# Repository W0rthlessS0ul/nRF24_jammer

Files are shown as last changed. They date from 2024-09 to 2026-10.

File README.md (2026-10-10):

<div align="center">
  
  <h1> 🌟 nRF24 Jammer 🌟 </h1>
</div>

Welcome to the **nRF24 Jammer** repository! 🎉 Dive into the world of RF interference with this unique project based on the ESP32 and nRF24 technology.

## 📚 Table of Contents
- [🚀 What Can You Do with This?](#-what-can-you-do-with-this)
- [📱 Ported Firmware](#-ported-firmware)
- [📟 Supported & Community PCBs](#-supported-&-community-pcbs)
- [📋 List of Components](#-list-of-components)
- [🧑‍🔧 Let's Get Started with Soldering!](#-lets-get-started-with-soldering)
- [🛠️ Build From Source](#-build-from-source)
- [📦 Flash Firmware](#-flash-firmware)
- [🎮 Device Control](#-device-control)
- [🌐 Web Interface](#-Web-Interface)
- [🔌 Serial Interface](#-Serial-Interface)
- [🎉 Final Outcome](#-final-outcome)
- [🙏 Acknowledgments](#-acknowledgments)
- [🤝 Project Supporters](#-project-supporters)
- [❤️ Support the project](#-support-the-project)
- [⭐ Star History](#-star-history)

-----

## 🚀 What Can You Do with This?
This amazing jammer is built on the **ESP32** architecture integrated with **configurable numbers of nRF24** modules. With its extraordinary capabilities, you can effectively disrupt signals across different technologies including:
- **Bluetooth** 🔊
- **BLE** 📱
- **Drones** 🚁
- **Wi-Fi** 📶
- **Zigbee**📡

-----

## 📱 Ported Firmware

| Device | Repository URL |
|---|---|
| Flipper Zero | [FZ_nRF24_jammer](https://github.com/W0rthlessS0ul/FZ_nRF24_jammer) |
| LOLIN32 Lite | [nRF24_jammer](https://github.com/gitati16/nRF24_jammer) |

-----

## 📋 List of Components
To bring this project to life, you will need the following components:

1. <details><summary><b>nRF24 modules 🛠️</b></summary>

    *Any nRF24 modules are suitable, but **CDEBYTE E01-2G4M27D** is recommended*

   </details>

2. **ESP-WROOM-32** ⚙️
3. **16V capacitors** rated at **100µF** 🔋
4. **128x32 or 128x64 OLED display** 📺 *(optional)*
5. **Tactile button** 🔘 *(optional)*

-----

## 📟 Supported & Community PCBs

| Preview | Author | Rev | Board README |
|---|---|-----|---|
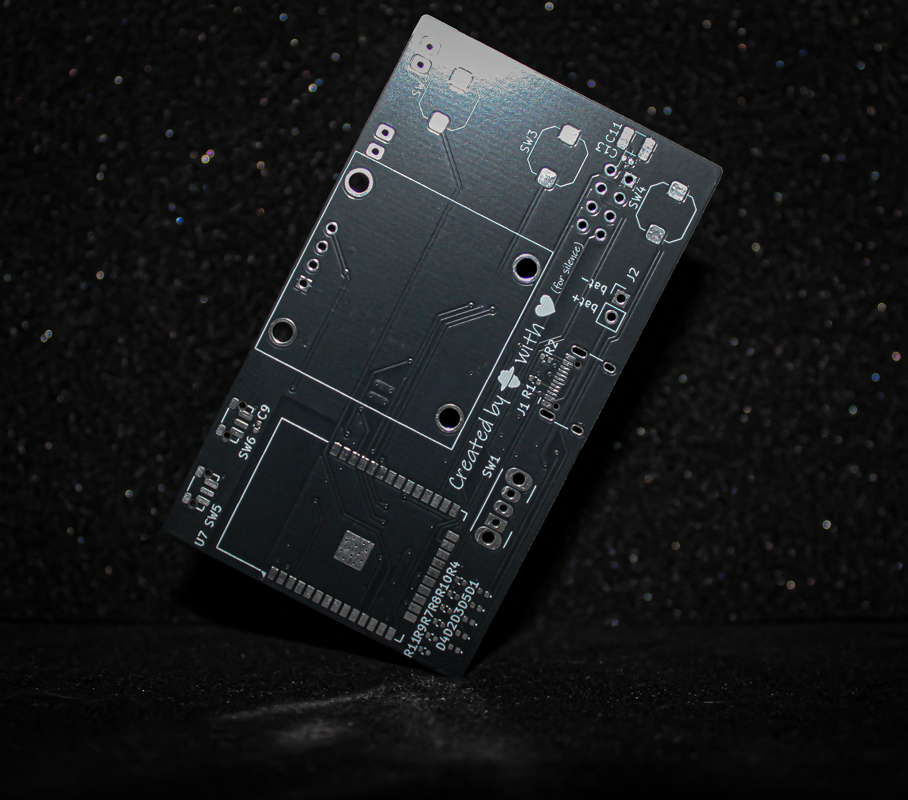
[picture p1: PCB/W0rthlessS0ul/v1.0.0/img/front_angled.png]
|  | [@W0rthlessS0ul](https://github.com/W0rthlessS0ul) | `v1.0.0` | [README](/PCB/W0rthlessS0ul/v1.0.0/README.md) |

> 💡 **Want to contribute your own PCB design?**  
> If you feel confident in designing a high-quality PCB, feel free to submit your board via a **Pull Request**!  
> 
> - **Well-engineered and verified designs** will be merged directly into the repository.  
> - If there are any doubts regarding layout quality, routing, or component selection, a thread will be opened in **[Discussions](https://github.com/W0rthlessS0ul/nRF24_jammer/discussions)** so the community can review, discuss, and vote on whether it should be added.

-----

## 🧑‍🔧 Let's Get Started with Soldering!

### Connecting First nRF24 module (**optional**)
| **Pin Name** | **ESP32 GPIO** | **Connection** |
|---|---|---|
| VCC | 3.3V | (+) capacitor |
| GND | GND | (-) capacitor |
| CE | GPIO 16 | |
| CSN | GPIO 15 | |
| SCK | GPIO 14 | |
| MOSI | GPIO 13 | |
| MISO | GPIO 12 | |
| IRQ | | |

### Connecting Second nRF24 module (**optional**)
| **Pin Name** | **ESP32 GPIO** | **Connection** |
|---|---|---|
| VCC | 3.3V | (+) capacitor |
| GND | GND | (-) capacitor |
| CE | GPIO 18 | |
| CSN | GPIO 17 | |
| SCK | GPIO 14 | |
| MOSI | GPIO 13 | |
| MISO | GPIO 12 | |
| IRQ | | |

### Connecting Third nRF24 module (**optional**)
| **Pin Name** | **ESP32 GPIO** | **Connection** |
|---|---|---|
| VCC | 3.3V | (+) capacitor |
| GND | GND | (-) capacitor |
| CE | GPIO 23 | |
| CSN | GPIO 19 | |
| SCK | GPIO 14 | |
| MOSI | GPIO 13 | |
| MISO | GPIO 12 | |
| IRQ | | |

### Connecting Fourth nRF24 module (**optional**)
| **Pin Name** | **ESP32 GPIO** | **Connection** |
|---|---|---|
| VCC | 3.3V | (+) capacitor |
| GND | GND | (-) capacitor |
| CE | GPIO 5 | |
| CSN | GPIO 4 | |
| SCK | GPIO 14 | |
| MOSI | GPIO 13 | |
| MISO | GPIO 12 | |
| IRQ | | |

### Connecting Fifth nRF24 module (**optional**)
| **Pin Name** | **ESP32 GPIO** | **Connection** |
|---|---|---|
| VCC | 3.3V | (+) capacitor |
| GND | GND | (-) capacitor |
| CE | GPIO 33 | |
| CSN | GPIO 32 | |
| SCK | GPIO 14 | |
| MOSI | GPIO 13 | |
| MISO | GPIO 12 | |
| IRQ | | |

### OLED Connection (**optional**)
| **Pin Name** | **ESP32 GPIO** |
|---|---|
| VCC | 3.3V |
| GND | GND |
| SCL | GPIO 22 |
| SDA | GPIO 21 |

### Button Connection (**optional**)
| **Button Actions** | **ESP32 GPIO** |
|---|---|
| OK | GPIO 25 |
| NEXT (Optional) | GPIO 26 |
| PREVIOUS (Optional) | GPIO 27 |

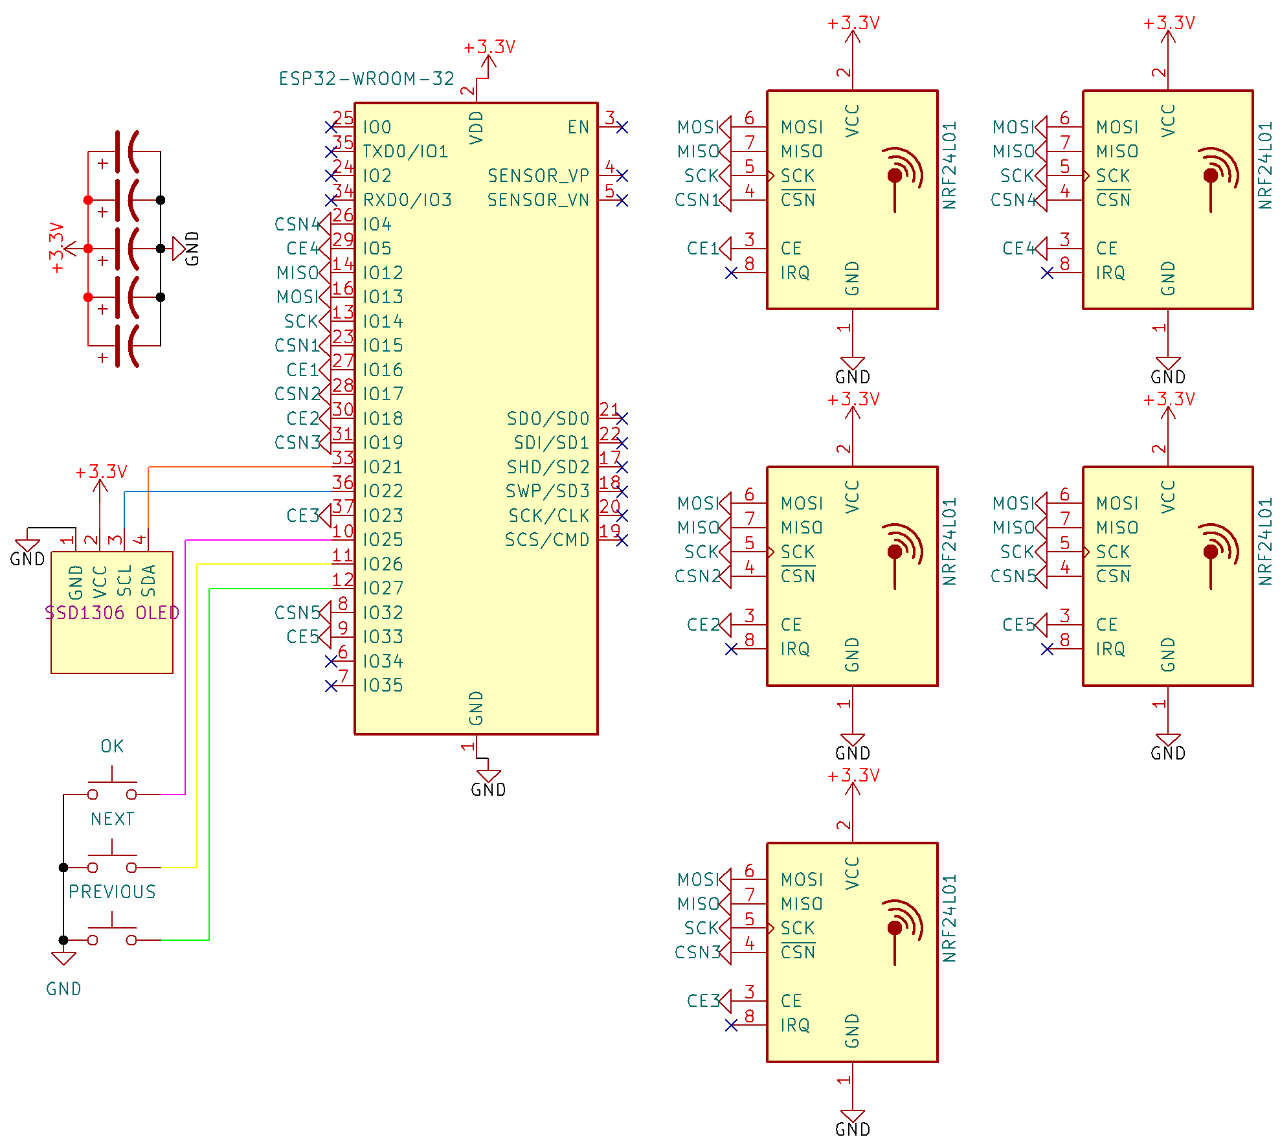
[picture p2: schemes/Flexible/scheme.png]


###### In all configurations the same SCK, MOSI, and MISO pins are used. This is not a mistake - SPI interfaces can share clock and data lines, while proper operation is ensured by separate control signals (CSN and CE)

-----

## 🛠️ Build From Source

#### `This section is addressed to contributors. If you are a regular user of the project, you can skip it`

1. Install **PlatformIO IDE** extension in **VS Code** 
2. Click the PlatformIO icon → Open → Open Project → select your project folder
3. Wait until all dependencies are installed
4. And now you can choose which project to compile in "PROJECT TASKS" or choose "Build all" to compile all kinds of firmware at once.
5. Output .bin files appear in: ```project_root/bin/[env_name]```

Build_From_Source

###### ⚠️ Important for source builds: Since v2.5.0, this project uses a modified RF24 library (see /lib).

-----

## 📦 Flash Firmware
<details>
<summary><strong>Manual Update</strong></summary>

<div style="margin-left: 20px;">

Follow these steps to flash the firmware:
1. Download the firmware from the **[releases](https://github.com/W0rthlessS0ul/nRF24_jammer/releases)** section that corresponds to your display
2. Navigate to **ESPWebTool**: [ESPWebTool](https://esp.huhn.me/)
3. Arrange the files as per the table below:

| **Address** | **File Name** |
|---|---|
| 0x1000 | bootloader.bin |
| 0x8000 | partitions.bin |
| 0x10000 | firmware.bin |

4. Click "Flash," and once the installation is complete, **restart your board** and enjoy using your jammer!

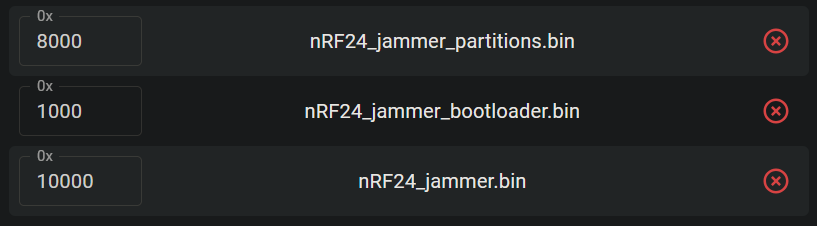
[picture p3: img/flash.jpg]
flash


</div>
</details>
<details>
<summary><strong>OTA Update</strong></summary>

<div style="margin-left: 20px;">

### This method can only be used if you have firmware version 1.9 or higher installed.
Follow these steps to flash the firmware:
1. Download the firmware from the **[releases](https://github.com/W0rthlessS0ul/nRF24_jammer/releases)** section that corresponds to your display
2. Turn on your device and open a web browser
3. Navigate to the web interface at **192.168.4.1**
4. Click on "**OTA**" and select the file "**firmware.bin**" (`⚠️️ make sure not to choose the bootloader or partitions files`)

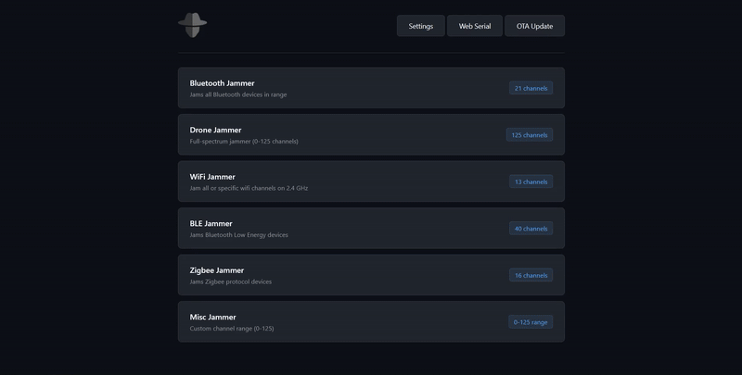
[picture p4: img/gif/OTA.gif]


</div>
</details>

-----

## 🎮 Device Control 

<details>
<summary><strong>🟢 1-Button Configuration</strong></summary>
<div style="margin-left: 20px;">

#### 📋 Menu Navigation
- **Short press** → Next menu item
- **Long press** → Select menu item

#### 📡 Misc Jammer
- **Short press** → Channel +1
- **Long press** → Continuous channel +1 (every 100ms)
- **Double press** → Select channel

#### 📡 WiFi Attack
- **Short press** → Stop attack
- **Double press** → Switch between jam\deauth

</div>
</details>

<details>
<summary><strong>🔵 2-Button Configuration</strong></summary>
<div style="margin-left: 20px;">

#### 📋 Menu Navigation
- **Next button** short press → Next menu item
- **OK button** short press → Select menu item

#### 📡 Misc Jammer
- **Next button** short press → Channel +1
- **Next button** long press → Continuous channel +1 (every 100ms)
- **OK button** short press → Select channel

#### 📡 WiFi Attack
- **Short press** → Stop attack
- **Next button** → Switch between jam\deauth

</div>
</details>

<details>
<summary><strong>🟣 3-Button Configuration</strong></summary>
<div style="margin-left: 20px;">

#### 📋 Menu Navigation
- **Next button** short press → Next menu item
- **Previous button** short press → Previous menu item
- **OK button** short press → Select menu item

#### 📡 Misc Jammer
- **Next button** short press → Channel +1
- **Next button** long press → Continuous channel +1 (every 100ms)
- **Previous button** short press → Channel -1
- **Previous button** long press → Continuous channel -1 (every 100ms)
- **OK button** short press → Select channel

#### 📡 WiFi Attack
- **Short press** → Stop attack
- **Next button** → Switch between jam\deauth
- **Previous button** → Switch between jam\deauth

</div>
</details>

-----

## 🌐 Web Interface

- To utilize the web interface, please follow the steps outlined below
1. activate the **nRF24 jammer**
2. Connect to the Wi-Fi network named `jammer` using the password `W0rthlessS0ul`
3. open your web browser and navigate to the IP address `192.168.4.1`
4. Now you can control your nRF24 jammer through an web interface

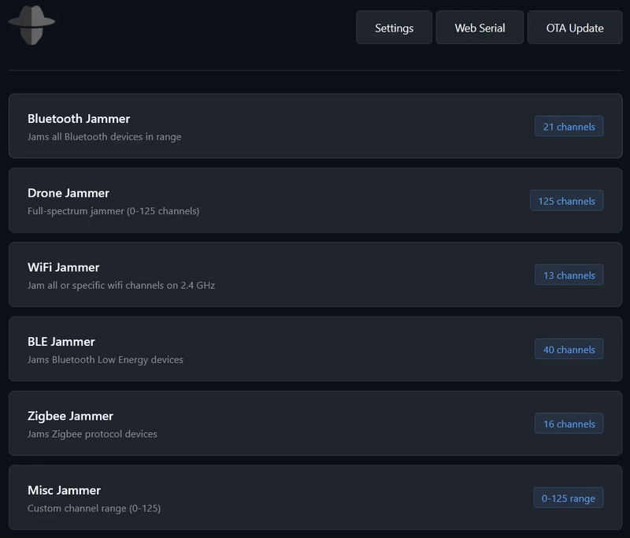
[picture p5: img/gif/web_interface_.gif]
web_interface


-----

## 🔌 Serial Interface

- To utilize the serial interface, please follow the steps outlined below
1. Activate the **nRF24 jammer**
2. Connect the device to a PC or phone via USB
3. You can use any serial terminals for control, for example: [spacehuhn terminal](https://terminal.spacehuhn.com/)
4. Now write **help** to get a list of commands

serial_interface

-----

## 🎉 Final Outcome

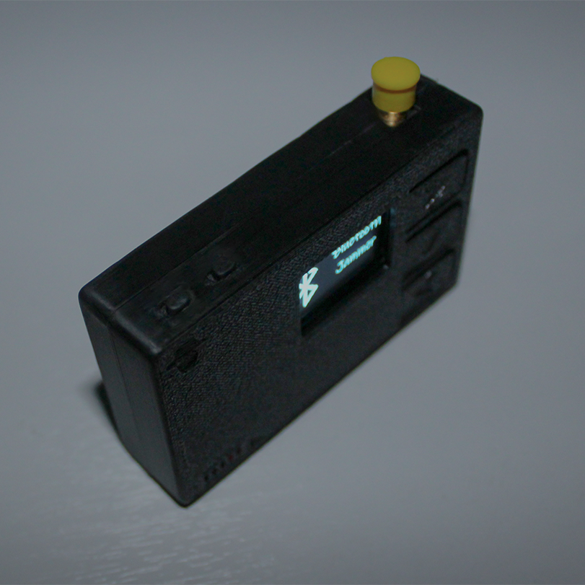
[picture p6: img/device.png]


### Normal Spectrum
Normal Spectrum

### Bluetooth Jam Spectrum
Bluetooth Jam Spectrum

### Drone Jam Spectrum
Drone Jam Spectrum

### Wi-Fi Jam Spectrum
Wi-Fi Jam Spectrum

### BLE Jam Spectrum
BLE Jam Spectrum

### Zigbee Jam Spectrum
Zigbee Jam Spectrum

### Misc Jam Spectrum
Misc Jam Spectrum

-----

## 🙏 Acknowledgments
- [smoochiee](https://github.com/smoochiee) - **for the main logic of the jammer.**
- [samukas81](https://github.com/samukas81) - **for suggesting ideas.**

-----

## 🤝 Project Supporters

| **Supporter** | **Contribution**|
|---|---|
|  [@sergey2735](https://github.com/sergey2735)  | 40.7 ADA |

-----

## ❤️ Support the Project

If you find this project useful and want to support its ongoing development, consider starring the repository ⭐, following the author, or buying a cup of coffee to keep things fueled! ☕

<div align="center">
  <table width="70%">
    <tr>
      <td width="50%" align="center">
        <a href="https://t.me/W0rthlessS0ul" target="_blank" rel="noreferrer noopener">
          Telegram Stars & Gifts
        </a>
      </td>
      <td width="50%" align="center">
        <a href="https://nowpayments.io/donation?api_key=6370NCF-SXJ4MMC-N71CVMS-6G52PW9" target="_blank" rel="noreferrer noopener">
          NOWPayments Crypto
        </a>
      </td>
    </tr>
  </table>
</div>

<br>

<details>
<summary><b>🪙 Direct Cryptocurrency Transfer</b></summary>
<br>

| Coin / Network | Direct Wallet Address |
| :--- | :--- |
| 🟧 **Bitcoin (BTC)** | `bc1qvul4mlxxw5h2hnt8knnxdrxuwgpf4styyk20tm` |
| 🔷 **Ethereum (ETH)** | `0x5c54eAb2acFE1c6C866FB4b050d8B69CfB1138Af` |
| ⚪ **Litecoin (LTC)** | `LbdzCsYbxuD341raar6Cg1yKavaDq7fjuV` |
| ⚫ **Ripple (XRP)** | `rKLLPzoBGfqY3pAQPwTFPRYaWjpHSwHNDw` |
| 🔵 **Cardano (ADA)** | `addr1qyz2aku0ucmxqnl60lza23lkx2xha8zmxz9wqxnrtvpjysgy4mdcle3kvp8l5l7964rlvv5d06w9kvy2uqdxxkcryfqs7pajev` |
| 🟡 **Dogecoin (DOGE)** | `DBzAvD62yQUkP4Cb7C5LuFYQEierF3D3oG` |

</details>

<br>

> Every donation is greatly appreciated and directly contributes to the development, testing, and new hardware revisions of this project!

---

## ⭐ Star History

<a href="https://star-history.dera.page/#W0rthlessS0ul/nRF24_jammer&type=date&legend=top-left">
 <picture>
   <source media="(prefers-color-scheme: dark)" srcset="https://star-history.dera.page/svg?repos=W0rthlessS0ul/nRF24_jammer&type=date&theme=dark&legend=top-left" />
   <source media="(prefers-color-scheme: light)" srcset="https://star-history.dera.page/svg?repos=W0rthlessS0ul/nRF24_jammer&type=date&legend=top-left" />
   Star History Chart
 </picture>
</a>

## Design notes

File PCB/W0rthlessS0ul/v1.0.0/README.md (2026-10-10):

<div align="center">

[⬅️ Back to Main Repository](/README.md)

# 📟 nRF24 Jammer Board (v1.0.0)

### Designed by [@W0rthlessS0ul](https://github.com/W0rthlessS0ul)

</div>

-----

## 📋 Board Specifications
* **MCU:** ESP-WROOM-32D
* **USB-to-UART:** CP2104
* **RF Modules:** One CDEBYTE E01-2G4M27D module
* **Display:** OLED 128x64
* **Controls:** 3 navigation buttons
* **Power Source:** 3.7V Li-Po battery with onboard Type-C charging circuit

-----

## ⚠️ Known Issues & Hardware Limitations

> **Please review the following hardware quirks of revision v1.0.0 before ordering and assembling:**

1. **Connected Battery Required (No Power Path):**  
   The board **cannot operate exclusively via USB Type-C without a battery connected**. It lacks a dedicated dynamic power-path management circuit. Without a battery, current is drawn directly through the onboard charging controller, which is capped at ~500mA. This is insufficient to handle simultaneous ESP32 transmission peaks and CDEBYTE module transmitting at full power, causing brownouts and bootloops
   
   👉 **A connected battery is strictly required for normal operation**
2. **Charging Status LED:**  
   In some instances, the charge status LED may remain dimly lit or fail to turn off completely even after the battery reaches full charge

-----

## 🖨️ 3D Enclosure

> **If you plan to use the 3D enclosure:**

- The case is specifically modeled for a **603450** Li-Po cell

-----

## 📸 Gallery

<div align="center">
  <table>
    <tr>
      <td align="center"><b>PCB Front</b></td>
      <td align="center"><b>PCB Back</b></td>
    </tr>
    <tr>
      <td></td>
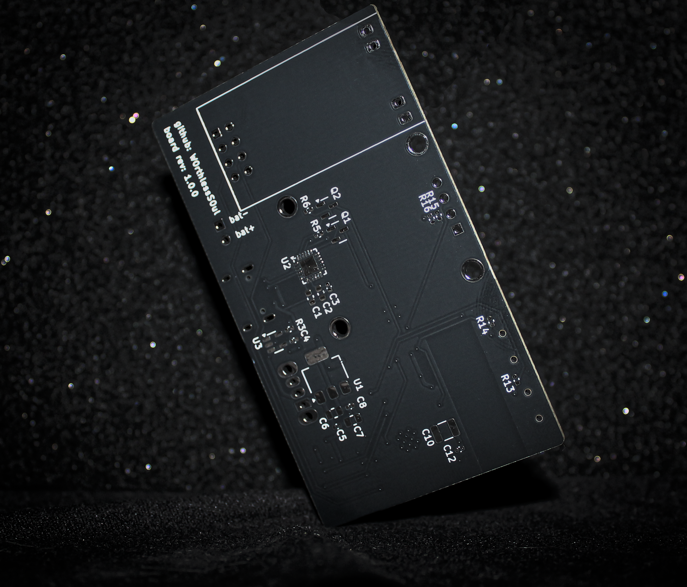
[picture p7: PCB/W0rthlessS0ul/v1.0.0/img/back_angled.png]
      <td></td>
    </tr>
    <tr>
      <td align="center"><b>3D Case (Solid)</b></td>
      <td align="center"><b>3D Case (X-Ray)</b></td>
    </tr>
    <tr>
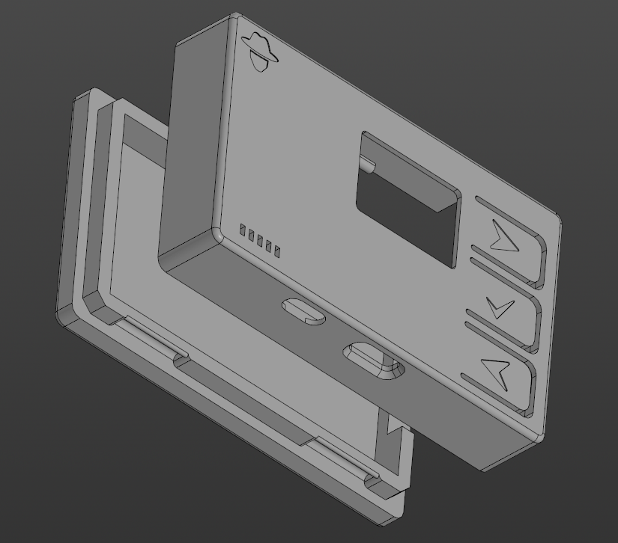
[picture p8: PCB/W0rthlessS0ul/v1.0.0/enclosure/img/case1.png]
      <td></td>
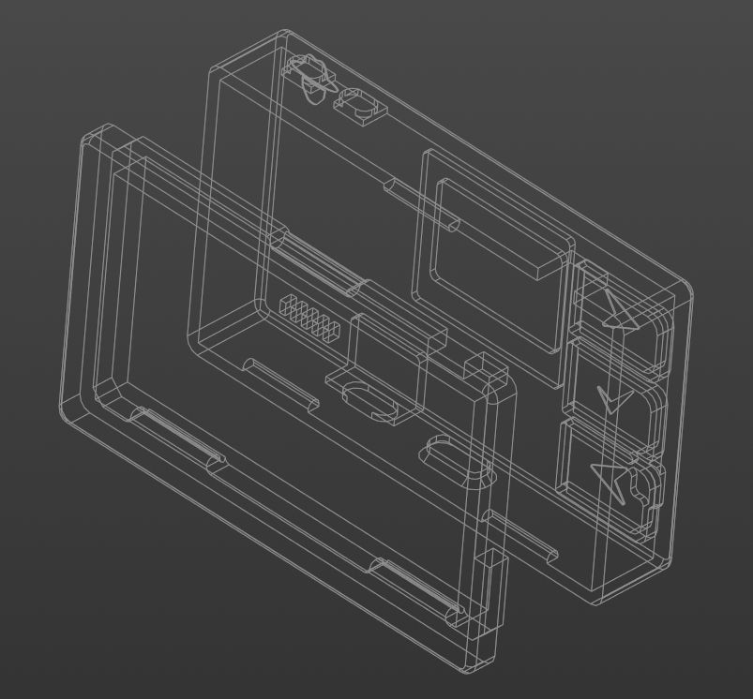
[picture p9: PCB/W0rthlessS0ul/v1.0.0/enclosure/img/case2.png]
      <td></td>
    </tr>
  </table>
</div>

-----

## 📦 Files

| Resource | Description | Link |
| :--- | :--- | :---: |
| 🗜️ **Gerber Files** | Production-ready archive | [Download ZIP](gerber/nRF24_jammer.zip) |
| 📝 **BOM** | Bill of Materials | [View BOM](bom/nRF24_jammer.csv) |
| 📐 **Schematic** | Electrical schematic | [Download PDF](/schemes/W0rthlessS0ul/v1.0.0/nRF24_jammer.pdf) |
| 🛠️ **KiCad Project** | Full project files | [Open Directory](kicad/) |
| 🖨️ **3D Enclosure** | Printable case models | [Open Directory](enclosure/) |

-----

## 📐 Electrical Schematic

<div align="center">

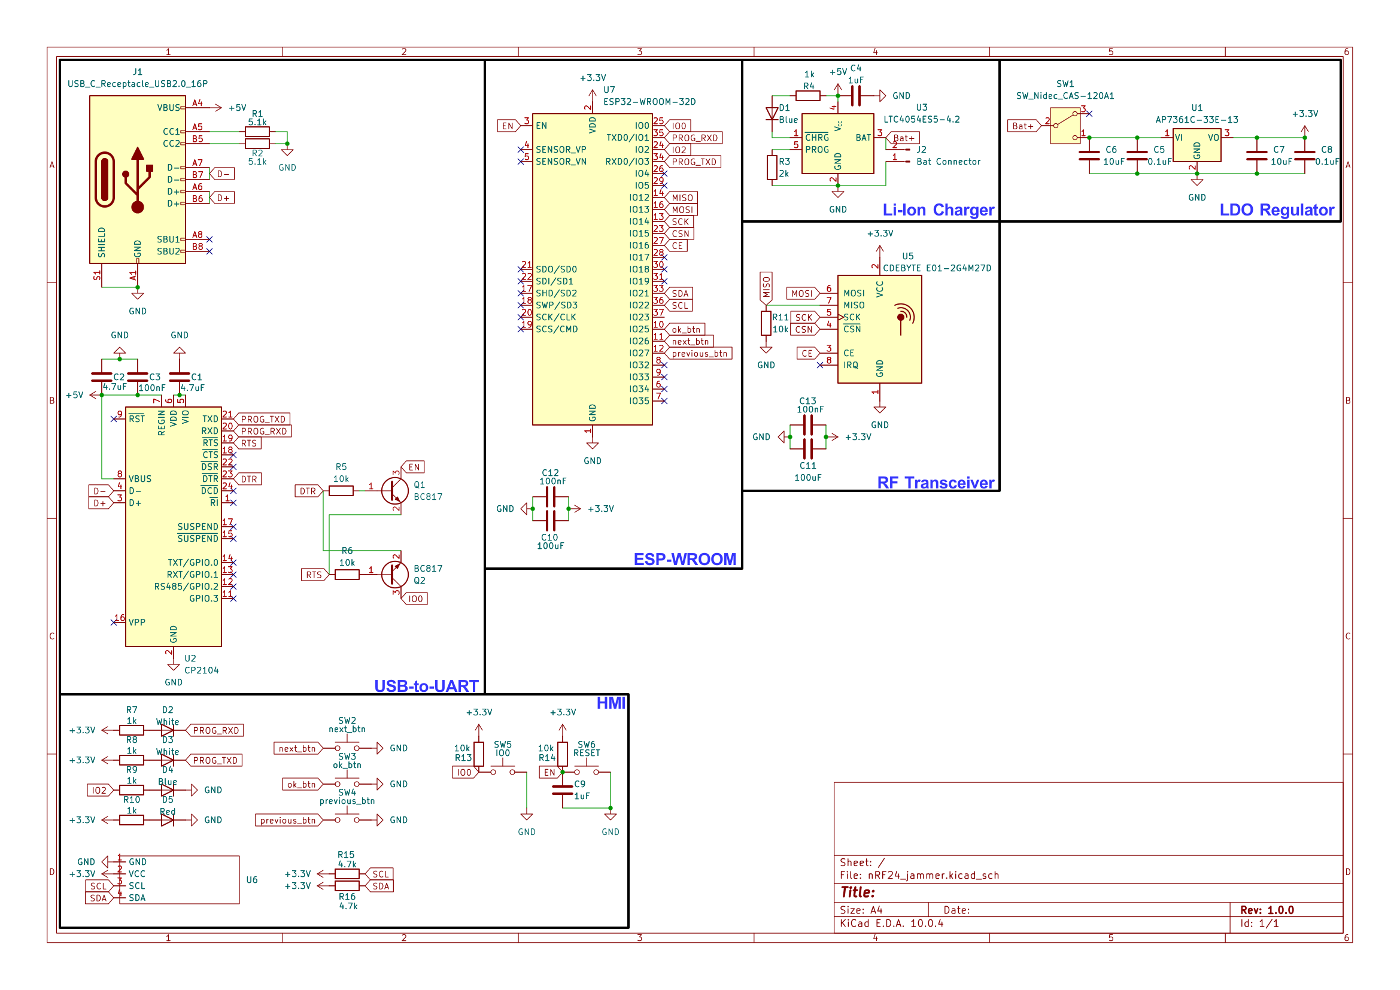
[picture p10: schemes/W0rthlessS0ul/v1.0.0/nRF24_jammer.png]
  <td></td>

</div>

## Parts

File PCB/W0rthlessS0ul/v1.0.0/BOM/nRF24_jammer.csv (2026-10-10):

Reference | Value | Footprint
C1,C2 | 4.7uF | Capacitor_SMD:C_0603_1608Metric
C3,C9 | 100nF | Capacitor_SMD:C_0402_1005Metric
C4 | 1uF | Capacitor_SMD:C_0402_1005Metric
C5,C8 | 0.1uF | Capacitor_SMD:C_0402_1005Metric
C6,C7 | 10uF | Capacitor_SMD:C_0805_2012Metric
C11 | 100uF | Capacitor_SMD:C_1210_3225Metric
D1,D4 | Blue | Diode_SMD:D_0402_1005Metric
D2,D3 | White | Diode_SMD:D_0402_1005Metric
D5 | Red | Diode_SMD:D_0402_1005Metric
J1 | USB_C_Receptacle_USB2.0_16P | Connector_USB:USB_C_Receptacle_HCTL_HC-TYPE-C-16P-01A
J2 | Bat Connector | Connector_PinHeader_2.54mm:PinHeader_1x02_P2.54mm_Vertical
Q1,Q2 | BC817 | Package_TO_SOT_SMD:SOT-23
R1,R2 | 5.1k | Resistor_SMD:R_0402_1005Metric
R3 | 2.5k | Resistor_SMD:R_0402_1005Metric
R4,R7,R8,R9,R10 | 1k | Resistor_SMD:R_0402_1005Metric
R5,R6 | 10k | Resistor_SMD:R_0402_1005Metric
R13,R14,R15,R16 | 4.7k | Resistor_SMD:R_0402_1005Metric
SW1 | SW_Nidec_CAS-120A1 | Button_Switch_THT:SW_Slide_SPDT_Angled_CK_OS102011MA1Q
SW2 | next_btn | Button_Switch_SMD:SW_Push_1TS009xxxx-xxxx-xxxx_6x6x5mm
SW3 | ok_btn | Button_Switch_SMD:SW_Push_1TS009xxxx-xxxx-xxxx_6x6x5mm
SW4 | previous_btn | Button_Switch_SMD:SW_Push_1TS009xxxx-xxxx-xxxx_6x6x5mm
SW5 | IO0 | Button_Switch_SMD:SW_Push_1P1T-MP_NO_Horizontal_Alps_SKRTLAE010
SW6 | RESET | Button_Switch_SMD:SW_Push_1P1T-MP_NO_Horizontal_Alps_SKRTLAE010
U1 | AP7361C-33E-13 | Package_TO_SOT_SMD:SOT-223-3_TabPin2
U2 | CP2104 | Package_DFN_QFN:QFN-24-1EP_4x4mm_P0.5mm_EP2.6x2.6mm
U3 | LTC4054ES5-4.2 | Package_TO_SOT_SMD:TSOT-23-5
U4 | ESP32-WROOM-32 | RF_Module:ESP32-WROOM-32
U5 | CDEBYTE E01-2G4M27D | nRF24_jammer:E01-2G4M27D
U6 |  | nRF24_jammer:Display 0.96 breakout board

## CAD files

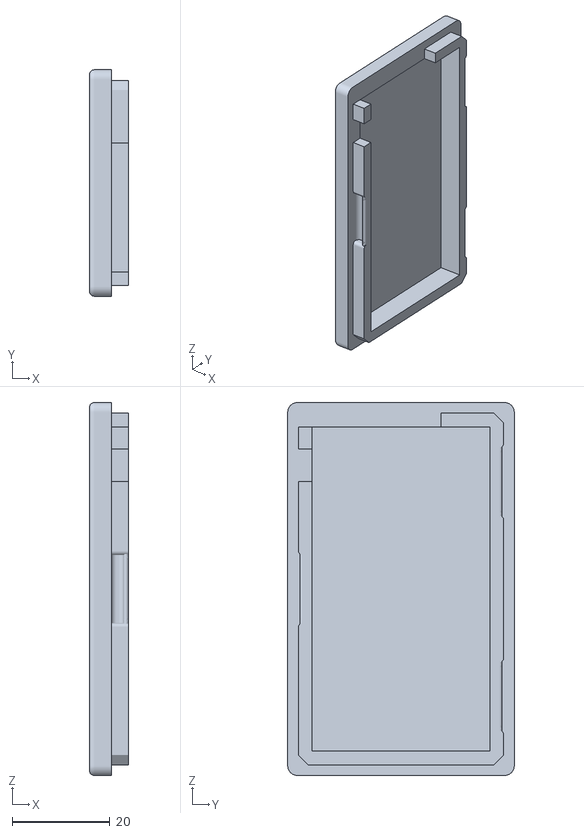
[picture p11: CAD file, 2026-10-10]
PCB/W0rthlessS0ul/v1.0.0/enclosure/caseBack.stl
8.00 x 46.4 x 76.4

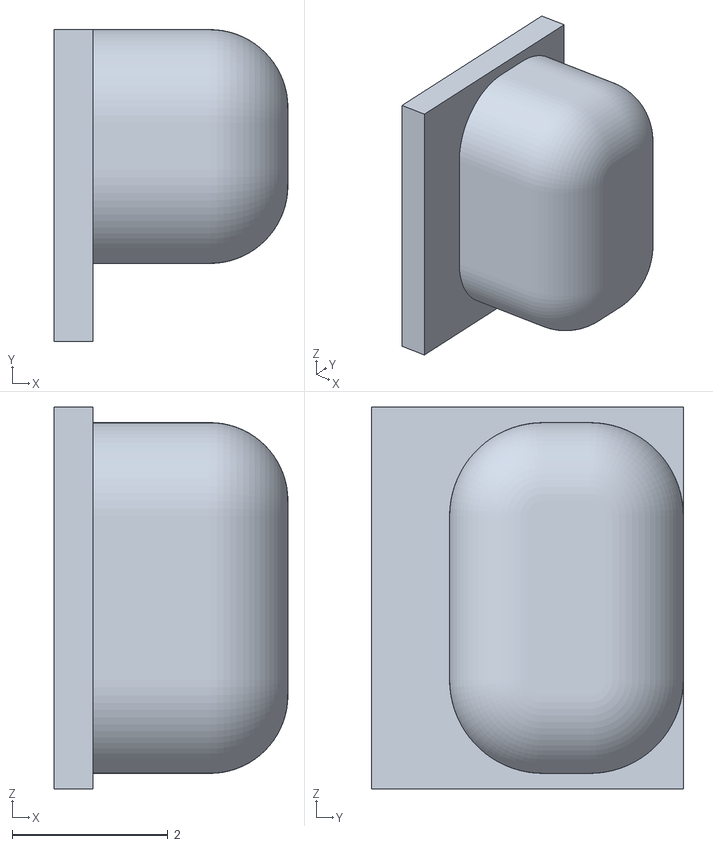
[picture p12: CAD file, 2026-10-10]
PCB/W0rthlessS0ul/v1.0.0/enclosure/button.stl
3.00 x 4.00 x 4.90

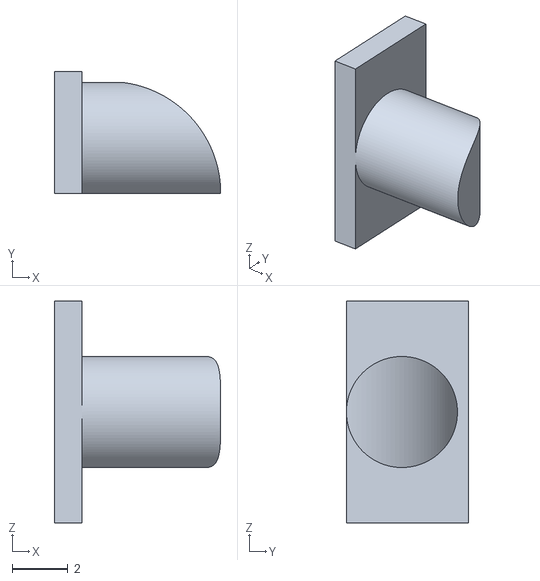
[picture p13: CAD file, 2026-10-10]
PCB/W0rthlessS0ul/v1.0.0/enclosure/switch.stl
6.00 x 4.40 x 8.00

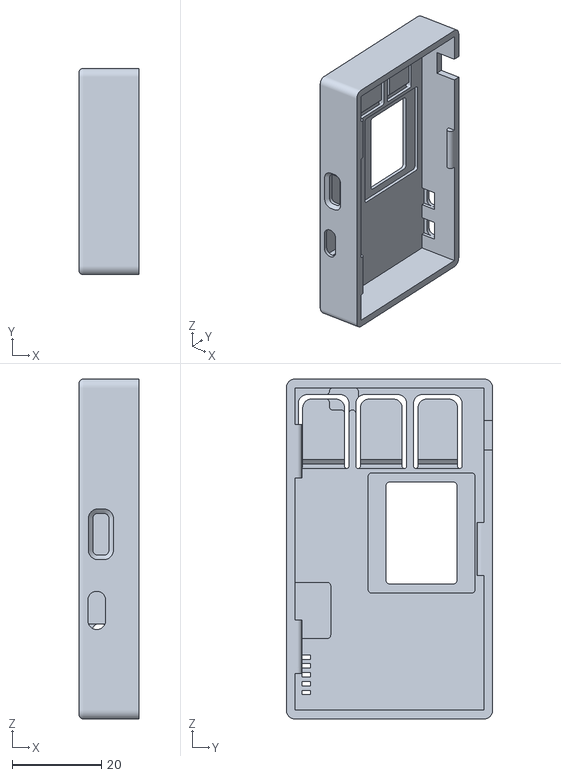
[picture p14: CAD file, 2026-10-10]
PCB/W0rthlessS0ul/v1.0.0/enclosure/caseFront.stl
13.5 x 46.4 x 76.4

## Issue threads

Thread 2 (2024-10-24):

error

samukas81, 2024-10-24:
Hello, how do I modify it to 128x64 OLED?
I modified it in Sketchup and recompiled it in .bin but it didn't work

W0rthlessS0ul, 2024-10-25:
Hello,

The display of images on the screen is achieved by modifying bitmap images. All images are currently set for a resolution of 128x32. In this message, I have attached a ZIP archive named jpg.zip containing .jpg images. Please resize them to 128x64 and update the entries in bitmap.h accordingly.
[jpg.zip](https://github.com/user-attachments/files/17515840/jpg.zip)

samukas81, 2024-10-25:
wow tnk's!!!

W0rthlessS0ul, 2024-10-25:
I was glad to help! If it’s not too much trouble, I would appreciate it if you could add my repository to your favorites. Doing so would greatly assist with its promotion. Thank you!

samukas81, 2024-10-25:
Yes I will add it, and congratulations, it works very well!

W0rthlessS0ul, 2024-10-25:
I'm glad to hear that! Wishing you successful usage.

samukas81, 2024-10-25:
sorry, is bitmap.h

W0rthlessS0ul, 2024-10-25:
Alright, I can modify the firmware for the 128x64 display. However, I don’t have that type of display on hand, so I won't be able to test it myself. After you update the firmware, I would appreciate it if you could send me a photo of the device. I'll do my best to send the modified firmware as soon as possible, probably within 1-2 hours, though it could be a bit earlier or later.

W0rthlessS0ul, 2024-10-25:
How would you prefer me to send the files: as .ino or .bin?

samukas81, 2024-10-25:
.ino please, thank you.

W0rthlessS0ul, 2024-10-25:
Could you please install this firmware and send a photo of what is displayed on your screen? Thank you!
[nRF24_jammer.zip](https://github.com/user-attachments/files/17522411/nRF24_jammer.zip)

samukas81, 2024-10-25:
show oled screen?

W0rthlessS0ul, 2024-10-25:
ya

samukas81, 2024-10-25:
It didn't work, I'm going back to the previous mode where I only changed the 128x64 of the OLED

https://github.com/user-attachments/assets/f07cc49a-3672-4453-8d08-07f277b807a3

W0rthlessS0ul, 2024-10-25:
Could you please clarify if the display showed anything on the previous firmware version?

samukas81, 2024-10-25:
Yes, it did, taking advantage of the subject, is there a way to modify it so that you don't need to turn off the power to be able to choose a new BLE, WiFi, etc. method?

samukas81, 2024-10-25:
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

W0rthlessS0ul, 2024-10-25:
Oh, I'm sorry! I thought your display wasn't working at all. In that case, please try this firmware.
[nRF24_jammer.zip](https://github.com/user-attachments/files/17522860/nRF24_jammer.zip)

W0rthlessS0ul, 2024-10-25:
Unfortunately, the display and the NRF24 module are connected to the same pins. As a result, the display can function initially while the NRF24 is not yet initialized. However, once the NRF24 is activated, the display will no longer work. Consequently, after the attack is launched, the only way to regain functionality is to reboot the device.

samukas81, 2024-10-25:
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

W0rthlessS0ul, 2024-10-25:
The image quality isn't the best, but at least it's functional. Thank you for helping me understand how the 128x64 display works. In the next update, I will try to add support for the 128x64 display. However, simply stretching the images isn't a viable solution.

If this option doesn't meet your needs, you can modify the imag
es to fit your resolution using the attached files, which are available in both .jpg and .psd formats. To convert the .jpg files into bitmap images, you can use the following tool: [img2cpp](https://javl.github.io/image2cpp/)
[img.zip](https://github.com/user-attachments/files/17522994/img.zip)

samukas81, 2024-10-25:
Thank you very much my friend to help

W0rthlessS0ul, 2024-10-25:
I believe we can consider this issue resolved—would you agree?

samukas81, 2024-10-25:
Yes!

W0rthlessS0ul, 2024-10-25:
Wishing you good luck, and goodbye for now!

Closed 2024-10-25.

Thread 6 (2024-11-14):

Copyright Infridgement

EmenstaNougat, 2024-11-14:
Copied parts of repository such as pinouts and inspiration/idea without credits.

https://github.com/EmenstaNougat/ESP32-BlueJammer

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

1:1 GPIO pinout as my ESP32-BlueJammer? This can't be a coincidence ;)

Jamming drones? Referred to my RC?

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

W0rthlessS0ul, 2024-11-14:
Hello, I’m afraid I was inspired not by your code, but rather by the code from this repository: https://github.com/smoochiee/Bluetooth-jammer-esp32.

W0rthlessS0ul, 2024-11-14:
By the way, thank you for reminding me to credit the author; I'll make sure to cite smoochiee right away.

EmenstaNougat, 2024-11-14:
Yeah, but I don't see my GPIO pinouts anywhere on smoochies repo

Am Do., 14. Nov. 2024 um 16:29 Uhr schrieb W0rthlessS0ul <
***@***.***>:

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

W0rthlessS0ul, 2024-11-14:
I could have credited you in the Acknowledgments section if I had taken a part of your code. However, I cannot include you simply for the similar tables we created.

W0rthlessS0ul, 2024-11-16:
Can we consider this issue resolved?

EmenstaNougat, 2024-11-16:
Sure

W0rthlessS0ul ***@***.***> schrieb am Sa., 16. Nov. 2024,
08:38:

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

smoochiee, 2024-11-28:
> I could have credited you in the Acknowledgments section if I had taken a part of your code. However, I cannot include you simply for the similar tables we created.

lol...why he think my repo dont have gpio pin out..🤔when its clearly there and he built my work before he started his...😂.shame

W0rthlessS0ul, 2024-11-28:
Who knew GPIO pinouts could spark such intense discussions? 😂 Next thing you know, we’ll be debating who invented the wheel!

Since Smoochiee released his work on March 6, 2024, and you posted yours later on July 7, 2024, and considering that your repository isn't open source, I can assert that you used Smoochiee's code when creating your repository.

So, I hope this clarifies things, and we won’t need to revisit this topic again!

EmenstaNougat, 2024-11-28:
I'm not about the jammer stuff

smoochiee ***@***.***> schrieb am Do., 28. Nov. 2024, 12:49:

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

Closed 2024-11-16.

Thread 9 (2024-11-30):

Wifi channel

samukas81, 2024-11-30:
Could you implement specific wifi channel selection to deauthenticate?

W0rthlessS0ul, 2024-11-30:
Hello, that's an interesting idea! I'll do my best to implement it in the next update.

samukas81, 2024-11-30:
Doing more tests, I discovered that in all modes after reset it still sends some kind of signal. Only when it turns off does it stop, but in Bluetooth mode after reset it stops the interference. Sorry for the video quality, I had to reduce the size to be able to post.

https://github.com/user-attachments/assets/ec3fee8d-7ae8-421b-9104-4eff3395272c

W0rthlessS0ul, 2024-11-30:
I'm not sure why, but the video you sent is opening as an MP3 file. Could you please create a repository and upload your video there so that I can watch it?

samukas81, 2024-11-30:
download the vídeo

samukas81, 2024-11-30:
Did you manage to watch the video?

W0rthlessS0ul, 2024-11-30:
I'm a little busy right now, sorry I can't take a look.

samukas81, 2024-11-30:
Don't worry, if you can't see it, let me know later, hugs.

W0rthlessS0ul, 2024-11-30:
I have a little bit of free time, but I might be unavailable again soon. I’m having trouble downloading your video. If it's not too much trouble, could you please send it to my email: [w0rthlesss00ul@gmail.com](mailto:w0rthlesss00ul@gmail.com)? Thank you!

W0rthlessS0ul, 2024-11-30:
An access point is being created on the ESP32, which also operates within the 2400 MHz to 2500 MHz range. However, my device does not transmit that much data, so either you are using an ESP32 with a more powerful transmitter (though that's unlikely), or there are issues with connecting the NRF24. It is definitely not a software issue, as the NRF24 is initialized only after the attack is launched.

samukas81, 2024-11-30:
How do I disable this access point that it creates, which lines do I disable in the sketch?

W0rthlessS0ul, 2024-11-30:
Please insert the following code into the nRF24_jammer.ino file:
#include "SPI.h"
#include "Update.h"
#include "EEPROM.h"
#include "Adafruit_GFX.h"
#include "Adafruit_SSD1306.h"
#include "GyverButton.h"
#include "RF24.h"
#include "bitmap.h"
#include "html.h"
#include "WiFi.h"
#include "WebServer.h"
#include "options.h"
#include "jam.h"

void handleRoot() {
    server.send(200, "text/html", html);
}

void sendHtmlAndExecute(const char* htmlResponse, void (*action)() = nullptr) {
    server.send(200, "text/html", htmlResponse);
    if (action) action();
}

void jamHandler(const char* htmlResponse, void (*jamFunction)()) {
    sendHtmlAndExecute(htmlResponse, jamFunction);
}

void miscChannelsHandler() {
    int channel1 = server.arg("start").toInt();
    int channel2 = server.arg("stop").toInt();
    sendHtmlAndExecute(html_misc_jam);
    misc_jam(channel1, channel2);
}

void settingsHandler(const char* htmlResponse) {
    sendHtmlAndExecute(htmlResponse);
}

void storeEEPROMAndSet(int index, int value, int& targetVar) {
    EEPROM.write(index, value);
    EEPROM.commit();
    targetVar = value;
    sendHtmlAndExecute(html);
}

void registerRoute(const char* path, void (*handler)()) {
    server.on(path, handler);
}

void handleFileUpload() {
    HTTPUpload &upload = server.upload();
    static unsigned long lastUpdate = 0;
    const unsigned long updateInterval = 100;

    if (upload.status == UPLOAD_FILE_START) {
        Serial.printf("Update: %s\n", upload.filename.c_str());
        if (!Update.begin(UPDATE_SIZE_UNKNOWN)) {
            Update.printError(Serial);
            server.send(200, "text/plain", "Update Failed");
            return;
        } else {
            server.sendContent(html_upload_progress);
            lastUpdate = millis();
        }
    }
    else if (upload.status == UPLOAD_FILE_WRITE) {
        if (Update.write(upload.buf, upload.currentSize) != upload.currentSize) {
            Update.printError(Serial);
        }

        if (millis() - lastUpdate >= updateInterval) {
            lastUpdate = millis();
            int progress = (100.0 * Update.progress() / Update.size());
            server.sendContent(String("<script>updateProgress(") + progress + ");</script>");
        }
    }
    else if (upload.status == UPLOAD_FILE_END) {
        if (Update.end(true)) {
            Serial.printf("Update Success: %u bytes\n", upload.totalSize);
            server.sendContent(String("<script>updateProgress(100); document.getElementById('status').innerHTML = 'Update Success';</script>"));
            delay(2000);
            ESP.restart();
        } else {
            Update.printError(Serial);
            server.sendContent("<script>document.getElementById('status').innerHTML = 'Update Failed';</script>");
        }
    }
}

void misc() {
    auto display_info = [&](String info) {
        display.clearDisplay();
        display.setCursor(0, 0);
        display.println("Start");
        display.setCursor(96, 0);
        display.println("Stop");
        display.setCursor(52, 0);
        display.println("Width");
        display.setCursor(8, 10);
        display.println(String(channel1));
        display.setCursor(60, 10);
        display.println(String(channel2 - channel1));
        display.setCursor(100, 10);
        display.println(String(channel2));
        display.setCursor(0, 20);
        display.println(info);
        display.display();
    };

    display.setTextColor(WHITE);
    display.setTextSize(1);
    display_info("");

    auto incrementChannel = [&](int& channel) {
        channel++;
        if (channel > 125) {
            channel = 0;
        }
    };

    while (true) {
        butt1.tick();

        if (butt1.isSingle() || butt1.isHold()) {
            if (butt1.isHold()) {
                delay(100);
            }
            incrementChannel(flag == 0 ? channel1 : channel2);
            display_info("");
        }
        else if (butt1.isDouble()) {
            if (flag == 0) {
                flag = 1;
            }
            else {
                if (channel1 > channel2) {
                    display_info("Error: Second < First");
                    flag = 0;
                }
                else {
                    display_info("Jamming Started");
                    misc_jam(channel1, channel2);
                }
            }
        }
    }
}

void setup() {
    Serial.begin(115200);
    EEPROM.begin(EEPROM_SIZE);

    // Initialize EEPROM values if unset
    for (int i = 0; i < 8; ++i) {
        if (EEPROM.read(i) == 255) {
            EEPROM.write(i, 0);
            EEPROM.commit();
        }
    }

    // Load settings
    bluetooth_jam_method = EEPROM.read(0);
    drone_jam_method = EEPROM.read(1);
    ble_jam_method = EEPROM.read(2);
    wifi_jam_method = EEPROM.read(3);
    Separate_or_together = EEPROM.read(4);
    zigbee_jam_method = EEPROM.read(5);
    misc_jam_method = EEPROM.read(6);
    logo = EEPROM.read(7);
    butt1.setTimeout(200);
    display.begin(SSD1306_SWITCHCAPVCC, 0x3C);
    if (logo == 0){
        display.clearDisplay();
        display.drawBitmap(0, 0, bitmap_logo, 128, 64, WHITE);
        display.display();
        delay(2000);
    }
    display.clearDisplay();
    display.drawBitmap(0, 0, bitmap_bluetooth_jammer, 128, 64, WHITE);
    display.display();
}

void loop() {
    butt1.tick();
    if (butt1.isSingle()) {
        menu_number = (menu_number + 1) % 6;
        display.clearDisplay();
        const uint8_t* bitmap = (menu_number == 0) ? bitmap_bluetooth_jammer :
                                (menu_number == 1) ? bitmap_drone_jammer :
                                (menu_number == 2) ? bitmap_wifi_jammer :
                                (menu_number == 3) ? bitmap_ble_jammer :
                                (menu_number == 4) ? bitmap_zigbee_jammer : bitmap_misc_jammer;
        display.drawBitmap(0, 0, bitmap, 128, 64, WHITE);
        display.display();
    }

    if (butt1.isHolded()) {
        if (menu_number == 5){
          misc();
        }
        display.clearDisplay();
        const uint8_t* bitmap = (menu_number == 0) ? bitmap_bluetooth_jam :
                                (menu_number == 1) ? bitmap_drone_jam :
                                (menu_number == 2) ? bitmap_wifi_jam :
                                (menu_number == 3) ? bitmap_ble_jam : bitmap_zigbee_jam;
        display.drawBitmap(0, 0, bitmap, 128, 64, WHITE);
        display.display();

        switch (menu_number) {
            case 0: bluetooth_jam(); break;
            case 1: drone_jam(); break;
            case 2: wifi_jam(); break;
            case 3: ble_jam(); break;
            case 4: zigbee_jam(); break;
        }
    }
}

W0rthlessS0ul, 2024-11-30:
Please insert the following code into the nRF24_jammer.ino file:
```#include "SPI.h"
#include "Update.h"
#include "EEPROM.h"
#include "Adafruit_GFX.h"
#include "Adafruit_SSD1306.h"
#include "GyverButton.h"
#include "RF24.h"
#include "bitmap.h"
#include "html.h"
#include "WiFi.h"
#include "WebServer.h"
#include "options.h"
#include "jam.h"

void handleRoot() {
    server.send(200, "text/html", html);
}

void sendHtmlAndExecute(const char* htmlResponse, void (*action)() = nullptr) {
    server.send(200, "text/html", htmlResponse);
    if (action) action();
}

void jamHandler(const char* htmlResponse, void (*jamFunction)()) {
    sendHtmlAndExecute(htmlResponse, jamFunction);
}

void miscChannelsHandler() {
    int channel1 = server.arg("start").toInt();
    int channel2 = server.arg("stop").toInt();
    sendHtmlAndExecute(html_misc_jam);
    misc_jam(channel1, channel2);
}

void settingsHandler(const char* htmlResponse) {
    sendHtmlAndExecute(htmlResponse);
}

void storeEEPROMAndSet(int index, int value, int& targetVar) {
    EEPROM.write(index, value);
    EEPROM.commit();
    targetVar = value;
    sendHtmlAndExecute(html);
}

void registerRoute(const char* path, void (*handler)()) {
    server.on(path, handler);
}

void handleFileUpload() {
    HTTPUpload &upload = server.upload();
    static unsigned long lastUpdate = 0;
    const unsigned long updateInterval = 100;

    if (upload.status == UPLOAD_FILE_START) {
        Serial.printf("Update: %s\n", upload.filename.c_str());
        if (!Update.begin(UPDATE_SIZE_UNKNOWN)) {
            Update.printError(Serial);
            server.send(200, "text/plain", "Update Failed");
            return;
        } else {
            server.sendContent(html_upload_progress);
            lastUpdate = millis();
        }
    }
    else if (upload.status == UPLOAD_FILE_WRITE) {
        if (Update.write(upload.buf, upload.currentSize) != upload.currentSize) {
            Update.printError(Serial);
        }
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
samukas81, 2024-11-30:
Does not compile

W0rthlessS0ul, 2024-12-01:
[nRF24_jammer.zip](https://github.com/user-attachments/files/17968532/nRF24_jammer.zip)
Install all the .bin files from the ZIP archive above onto your ESP32.

W0rthlessS0ul, 2024-12-09:
> Could you implement specific wifi channel selection to deauthenticate?

Your idea has been successfully implemented, so we can consider the issue resolved. Do you agree?

samukas81, 2024-12-09:
yes

W0rthlessS0ul, 2024-12-09:
Good luck! If you have any more ideas to contribute, feel free to create additional issues and share your suggestions there.

samukas81, 2024-12-09:
Congratulations on your commitment!!

W0rthlessS0ul, 2024-12-09:
Thank you! I appreciate your support and feedback. It motivates me to keep improving the project!

Closed 2024-12-09.

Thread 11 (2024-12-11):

Add support  BW16

Cloudplayer, 2024-12-11:
Can you add support for BW16? It supports WiFi 2.4GHz and 5GHz. Thank you !

W0rthlessS0ul, 2024-12-11:
Hello, do you want to use BW16 to create a web interface access point? Or do you want to use it for jamming?

W0rthlessS0ul, 2024-12-12:
Unfortunately, the BW16 module is not suitable for jamming. In repository, I specifically used 2 nrf24 modules to jam channels. The BW16 is similar to the esp32 module, which can only be used as a controller.

samukas81, 2024-12-12:
https://github.com/n0tAv1ru5/RTL8720dn-5GHz-Wifi-Deauther

Yes, it is possible to do it, take a look at the rtl8720dn deauthenticator, if you can implement OLED it would be perfect

W0rthlessS0ul, 2024-12-13:
The main issue is that adding a function like a deauther would disrupt the core concept of my repository. The name itself is "jammer," not "universal tool." However, there is currently a vote underway regarding a potential change to the concept, and you can participate in the [discussion](https://github.com/W0rthlessS0ul/nRF24_jammer/discussions/12).

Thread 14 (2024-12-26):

Add more buttons

shuixing1122, 2024-12-26:
https://github.com/user-attachments/assets/e9f2d285-0a6e-4bd0-b124-eb16e9ed7a49
Hello, could you please add more buttons to control? Only one button is too troublesome to control. Just like that video, there are four buttons, up and down, OK and return. It's very convenient to operate like this.

W0rthlessS0ul, 2024-12-30:
Hello, this is a great idea! However, in order to update the firmware without errors, I need to create another device. Unfortunately, I currently have very limited funds, so I will have to attempt this later when my financial situation improves.
But thank you for the great idea!

shuixing1122, 2024-12-31:
I saw on other forums that someone else adopted your firmware and also made a PCB board, the effect looks really cool, looking forward to your new firmware😊

https://github.com/user-attachments/assets/1c7d1b52-f10f-476f-9bea-cb57e9d3245d

W0rthlessS0ul, 2025-02-06:
Hello again! Sorry for the delay in releasing updates. I had some issues that prevented me from working on GitHub for a while, but I'm excited to share that your suggestion has been included in the latest update!

W0rthlessS0ul, 2025-02-07:
Can we consider this issue resolved?

Closed 2025-02-07.

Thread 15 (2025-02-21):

Next and previous buttons are still not working

Itsdipper, 2025-02-21:

W0rthlessS0ul, 2025-02-21:
Hello, you need to specify how many buttons to use in the settings. You can connect to the access point that the device creates and navigate to http://192.168.4.1/setting_buttons and then select "Three-button control (25, 26, 27 pin)"

W0rthlessS0ul, 2025-02-21:
Alternatively, you can go to "Settings", "Buttons" on 192.168.4.1 and select "Three-button control (25, 26, 27 pin)"

W0rthlessS0ul, 2025-02-21:
Did it help solve the problem?

Itsdipper, 2025-02-21:
Yeah, now it's working!! Thanks dude! ❤️

Itsdipper, 2025-02-21:
Sir, Can I hide or change access point that the device created?

W0rthlessS0ul, 2025-02-21:
There is a function in the settings to disable the access point. But there is no name change feature yet, I will try to add it in the next update.

Itsdipper, 2025-02-21:
Okay thankyou for help ❤️

W0rthlessS0ul, 2025-02-22:
I'm glad I could be of help. Have a good day!

W0rthlessS0ul, 2025-04-26:
Hello again, your idea has been added.

Itsdipper, 2025-04-26:
Thanks again ✨

Closed 2025-02-22.

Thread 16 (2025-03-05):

Switch jamming modes using boot button (GPIO0) on ESP32

VNEvil, 2025-03-05:
Hello @W0rthlessS0ul !
In the nRF24_jammer Without OLED project, would it be possible to add a function to switch between basic jamming modes using the boot button (GPIO0) on the ESP32? I find this feature very convenient.
Thank you!

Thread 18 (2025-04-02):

Can you elaborate the process for inputing code, soldering, etc for noobies like me?(maybe like a vid or smth)

MaximusMan11, 2025-04-02:
Basically, what the title says^

W0rthlessS0ul, 2025-04-05:
Hello! I will add a video about flashing the firmware, but I probably won't be able to add a video on soldering.

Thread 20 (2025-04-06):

Hello. Where can I find the wiring diagrams?

S1kser, 2025-04-06:

W0rthlessS0ul, 2025-04-06:
Hello, wiring diagrams are available in the form of a table. You can find them at this [link](https://github.com/W0rthlessS0ul/nRF24_jammer?tab=readme-ov-file#-lets-get-started-with-soldering). Select the version of the device you want to assemble from the dropdown menu.

Closed 2025-04-06.

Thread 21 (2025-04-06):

The button is connected to GPIO# and to GND or 3.3v or other

S1kser, 2025-04-06:

W0rthlessS0ul, 2025-04-06:
Hello, the buttons should be connected to GPIO# and GND

S1kser, 2025-04-07:
how  Bluetooth differs from BLE?

W0rthlessS0ul, 2025-04-07:
BLE, or Bluetooth Low Energy, uses channels 37, 38, and 39. BLE is commonly used in smartwatches, control systems, temperature sensors, and various management applications.

Bluetooth is the standard protocol that utilizes channels ranging from 0 to 78 and is widely used in devices such as headphones and speakers.

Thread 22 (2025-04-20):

Low range

narrwass, 2025-04-20:
How can i extend the range of the bluetooth jammer?
Im connecting my phone with my car stereo and the jammer needs to be in the range of 2 meters to stop the music.

Ive connected the 3.3V to the esp 3.3V pin.Maybe use external power supply? Didnt measured the voltage drop but the display is powered by the same pin and its ok.
Using the one anthena module version with jammer_C_32 code.

W0rthlessS0ul, 2025-04-20:
Hello, you can buy a 2.4 Ghz amplifier and connect the jammer to the RFin input and the antenna to the RFout (for example, I use a 1 Watt TZT RF2126).

You can also use a directional antenna, it also greatly increases the range of operation (I use NOWEPOCH 2.4G WIFI at 18dBi).

djmuerteitm, 2025-07-16:
You can use Ebyte 2G4M27 modules instead "basic" nrf24. Ebyte can tx Up to 27db, and with standard build setup (2 modules) and proper antennas you can extend the range above 10 or 20 meters for easy (outdoors)

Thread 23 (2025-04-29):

Buttons problem

Itsdipper, 2025-04-29:
Hey, when I Added the ability to exit the jamming mode by pressing the OK button then the jammer stop working properly

W0rthlessS0ul, 2025-04-29:
Can you tell me what exactly happened? And best of all, send the video by [email](mailto:w0rthlesss00ul@gmail.com).

KIK0092, 2025-10-06:
bonjour jaimerais savoir jai le bouton pin 25 qui fonctionne bien mais le 26 et 27 ne fonctionnent pas

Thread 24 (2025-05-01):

What type of esp32?

zelamuss, 2025-05-01:
you wrote esp32 30 pin on the ingredients(yes,ingredients).but there is a lot of esp32 30 pin versions,like wroom-32u wroom-32e.
even if it doesnt matter you can write (version doesnt matter) to avoid confusion.

i sound like a nerd

also,im thinking of adding cc1101 to this project,can you give me some tips? its my first time doing something like this.

W0rthlessS0ul, 2025-05-01:
You're right, I'm going to change the description now, I'm using ESP32-DevKitC, but you can also use ESP32-DevKit V1.

As for cc1101, I advise you to look towards [cc1101_tool](https://github.com/mcore1976/cc1101-tool).

W0rthlessS0ul, 2025-05-01:
The inaccuracy has been fixed, so can I close the issue?

Closed 2025-05-02.

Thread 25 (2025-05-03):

WHere are the .bin files located?

bfpa40, 2025-05-03:
I am assembling the jammer without the display but I cannot find the "releases" section you reference in order to download the 3 .bin files needed

bfpa40, 2025-05-04:
After looking and looking i found them so problem solved!

W0rthlessS0ul, 2025-05-04:
now the "releases" button translates to the page: https://github.com/W0rthlessS0ul/nRF24_jammer/releases

Closed 2025-05-04.

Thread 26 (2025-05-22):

Freeze

samukas81, 2025-05-22:
Hello friend, when I press the button to stop the attack it stops, but the screen freezes and nothing else works.

W0rthlessS0ul, 2025-05-23:
Hello, to help, I need to know:

1. Which release do you use
2. When exiting from which attack (bluetooth, drone, ble or something else), the jam occurred
3. If possible, could you describe in detail what steps you took before the error occurred so that I can reproduce it?

samukas81, 2025-05-23:
I tested with the latest and penultimate version, same problem. The problem occurs with any attack method. I installed it both via OTA and directly via Arduino V2.

samukas81, 2025-05-25:
Another problem I found was that even after stopping the attack, the modules remain activated with tree

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

 carriers in the band. It only turns off by removing the power supply.

W0rthlessS0ul, 2025-05-26:
The problem with the module remaining active has been fixed in release V2.5.0
Regarding the issue with hang, I was unable to replicate this error. Could you please send [me](mailto:w0rthlesss00ul@gmail.com) a video demonstrating what you are doing and why the issue is occurring?

W0rthlessS0ul, 2025-06-01:
Hello again, I understand what you were talking about, I will try to fix it soon.

samukas81, 2025-06-03:
Hello again, now it's fine but it still has active carriers after canceling the attack.

samukas81, 2025-06-03:
In all!!

W0rthlessS0ul, 2025-06-03:
Okay, I'll see if it can be fixed

samukas81, 2025-06-15:
Hello, did you manage to fix it?

W0rthlessS0ul, 2025-06-16:
Hello, I'm afraid I haven't been able to find this problem, here's what my spectrum looks like:

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

As you can see, after stopping the jammer, the spectrum remains the same as it was before

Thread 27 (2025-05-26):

Esp32 Wroom

Trust3555, 2025-05-26:
Hi!
I have only 1 question for your cc1101 jammer:
I have esp32 Wroom 32d. Is it ok for this project?
Thank you very much! Mario

Closed 2025-05-26.

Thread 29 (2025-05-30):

Where are the schematics for the required HW?

eabase, 2025-05-30:
Hi,
Very cool project!

However, I'm missing the schematics (or links to) for the required hardware.
I have some ESP32 pieces and some nRF52840 stuff. Can they be used?

I'm working on a Deauth for the ESP...

eabase, 2025-06-01:
> Did you even read the readme? Very first page.

I did, and I don't see a BOM nor a board or Schematic on how you connected the devices together. As I'm looking to try to use my own devices, that would be very helpful.

If you don't have it, or can't explain it, maybe you can provide some more closeup photos of the breadboard you're using?

W0rthlessS0ul, 2025-06-01:
Hello, in README.md there is a section called "🧑🔧 Let's Get Started with Soldering!" in which the "With OLED" and "Without OLED" drop-down windows select the version you want to assemble or you can watch it below:

## 🧑‍🔧 Let's Get Started with Soldering!
<details>
<summary><strong>With OLED</strong></summary>

<div style="margin-left: 20px;">

## Differences between versions

The **Compact** version is equipped with a **single NRF24** module, while the **Standard** version features **two**.

Notably, the Compact version allows **uninterrupted access to the display** even when jamming is started.

This will enable me to utilize features that may be added in the future but are currently **unavailable** in the **Standard version**. For instance, **one already implemented** feature is the a**bility to exit jamming mode** by simply pressing the "**OK**" button (*pin 25*).

Given these advantages, **I highly recommend choosing the Compact version** for its versatility and potential for future enhancements.

---

<details>
<summary><strong>Compact</strong></summary>

<div style="margin-left: 20px;">

### HSPI Connection
| **Pin Name** | **ESP32 GPIO** | **Connection**       |
|--------------|----------------|----------------------|
| VCC          | 3.3V          | (+) capacitor        |
| GND          | GND           | (-) capacitor        |
| CE           | GPIO 16       |                      |
| CSN          | GPIO 15       |                      |
| SCK          | GPIO 14       |                      |
| MOSI         | GPIO 13       |                      |
| MISO         | GPIO 12       |                      |
| IRQ          |                |                      |

### OLED Connection
| **Pin Name** | **ESP32 GPIO** |
|--------------|----------------|
| VCC          | 3.3V          |
| GND          | GND           |
| SCL          | GPIO 22       |
| SDA          | GPIO 21       |

### Button Connection
| **Button Actions** | **ESP32 GPIO** |
|--------------|----------------|
| OK          | GPIO 25       |
| NEXT (Optional)             | GPIO 26       |
| PREVIOUS (Optional)            | GPIO 27       |

</div>
</details>

<details>
<summary><strong>Standard</strong></summary>

<div style="margin-left: 20px;">

### HSPI Connection
| **Pin Name** | **ESP32 GPIO** | **Connection**       |
|--------------|----------------|----------------------|
| VCC          | 3.3V          | (+) capacitor        |
| GND          | GND           | (-) capacitor        |
| CE           | GPIO 16       |                      |
| CSN          | GPIO 15       |                      |
| SCK          | GPIO 14       |                      |
| MOSI         | GPIO 13       |                      |
| MISO         | GPIO 12       |                      |
| IRQ          |                |                      |

### VSPI Connection
| **Pin Name** | **ESP32 GPIO** | **Connection**       |
|--------------|----------------|----------------------|
| VCC          | 3.3V          | (+) capacitor        |
| GND          | GND           | (-) capacitor        |
| CE           | GPIO 22       |                      |
| CSN          | GPIO 21       |                      |
| SCK          | GPIO 18       |                      |
| MOSI         | GPIO 23       |                      |
| MISO         | GPIO 19       |                      |
| IRQ          |                |                      |

### OLED Connection
| **Pin Name** | **ESP32 GPIO** |
|--------------|----------------|
| VCC          | 3.3V          |
| GND          | GND           |
| SCL          | GPIO 22       |
| SDA          | GPIO 21       |

### Button Connection
| **Button Actions** | **ESP32 GPIO** |
|--------------|----------------|
| OK          | GPIO 25       |
| NEXT (Optional)             | GPIO 26       |
| PREVIOUS (Optional)            | GPIO 27       |

</div>
</details>

</div>
</details>
<details>
<summary><strong>Without OLED</strong></summary>

<div style="margin-left: 20px;">

### HSPI Connection
| **Pin Name** | **ESP32 GPIO** | **Connection**       |
|--------------|----------------|----------------------|
| VCC          | 3.3V          | (+) capacitor        |
| GND          | GND           | (-) capacitor        |
| CE           | GPIO 16       |                      |
| CSN          | GPIO 15       |                      |
| SCK          | GPIO 14       |                      |
| MOSI         | GPIO 13       |                      |
| MISO         | GPIO 12       |                      |
| IRQ          |                |                      |

### VSPI Connection
| **Pin Name** | **ESP32 GPIO** | **Connection**       |
|--------------|----------------|----------------------|
| VCC          | 3.3V          | (+) capacitor        |
| GND          | GND           | (-) capacitor        |
| CE           | GPIO 22       |                      |
| CSN          | GPIO 21       |                      |
| SCK          | GPIO 18       |                      |
| MOSI         | GPIO 23       |                      |
| MISO         | GPIO 19       |                      |
| IRQ          |                |                      |

</div>
</details>

-----

connor33341, 2025-06-02:
I have a kicad schematic, it's a very bare-bones version of the compact jammer. It also "technically" has a bom. The files are in the .zip, so you can edit it, or make it into a pcb, or whatever.
[hardware.zip](https://github.com/user-attachments/files/20543201/hardware.zip)
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

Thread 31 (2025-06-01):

Problem with Button performance

McVillano, 2025-06-01:
Hello,

First of all thank you for this cool project. I have one problem and one question.

The problem when i swich the button mode on the webpage to 3 buttons, they stop working, don't know why:

https://github.com/user-attachments/assets/70257df1-55a6-4515-9f56-e2b07a089bca

Randomly one button works but not consistent.

The question, wich is the logic in the menus for the one button navigation, i feel it would be usefull to add to the README.
I've guessed that it press to go to the next item in menu and long press to enter, but it would be cool to know.
Also i feel like the difference between press and long-press is too little, i don't know if this can be changed, but it would be cool to maybe get like 2-3s press, in mine i feel like i long press without wanting frecuently.

Also i would like to know wich is the stop attack button combination.

https://github.com/user-attachments/assets/b49d0b94-23f0-436b-80ed-71baa31881e3

Video of the one button

Thanks in advance

eabase, 2025-06-01:
IDK, know, but this sounds like a button *debounce* issue.
I bet your FW or circuit has no debounce function built-in.

https://www.picotech.com/library/articles/blog/what-is-switch-bounce-how-to-implement-debounce
https://docs.arduino.cc/built-in-examples/digital/Debounce/
https://electronics.stackexchange.com/questions/694167/should-i-debounce-everything

Linking: #21 and #23

McVillano, 2025-06-01:
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

Thanks for the answer, what you mention is likely happening in the second vídeo, i will try yo add a resistor and a capacitor like the link you sent said or buy new better buttons

We still don’t know why when i set config mode for 3 buttons non of them work

W0rthlessS0ul, 2025-06-01:
Hello, you're right, I'll try to add a delay and help with control in the near future (thanks for the idea)

But I didn't fully understand what exactly happens when you switch to 3 buttons, you can send a video with exactly what happens.

W0rthlessS0ul, 2025-06-02:
Your idea was added, but I couldn't recreate the error you mentioned.

Closed 2025-06-03.

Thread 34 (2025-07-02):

There is no click "stop"

Dead3ch, 2025-07-02:
Hello. I connected to the web interface, turned on Bluetooth, turned on the attack on Bluetooth, but I can not stop, how to stop these attacks ? There is no click "stop"

djmuerteitm, 2025-07-16:
Clic stop = N.O. button
Pin: EN --> GND

Push = reset mcu = stop

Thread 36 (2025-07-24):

Stuck on connecting the second module nrf24

Dead3ch, 2025-07-24:
Hi, help me I didn't understand, I connected the first NRF24 module, but I got stuck on connecting the second NRF24 module, where should the jumper wire from the second VCC module lead if 3v3 is occupied by the first contact of the NRF24 ?

W0rthlessS0ul, 2025-07-25:
The second wire must also be connected to the same 3.3V pin. To do this, you need to connect the wires, for example, simply solder them or use a terminal

Dead3ch, 2025-07-25:
and what about the GND connection ?

W0rthlessS0ul, 2025-07-25:
If there are two GND pins on the board, then simply connect the wires to different pins, if there is one pin, then connect it in the same way as in the case of the 3.3V pin.

GKDRBQ, 2025-08-05:
Hello, I like what you made very much. I'm using nrf24. It's easy for the interface to crash. It's suspended and can't be used. flipper

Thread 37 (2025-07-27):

More brain storm - NOT ISSUE

djmuerteitm, 2025-07-27:
Hi again, W0rTh.

I have three M5stickC (non plus, 1st gen) and one M5Core2.

What you think about do some play around this stuff? Is there a way to interface It with one (at least) or two nrf24 modules and run the jammer on them? Like "micro version" or "easy interfacing"...

Im able for beta-test if you want... I'll back from hdays next 15th aug... I'll come with fresh news about the performance and range of my dual 2G4M27 jammer, tested with both antennas (omni and dir) and all jam modes... Im pretty sure It will works hard for every days...

Thanks in advance!

W0rthlessS0ul, 2025-07-27:
Hi, it's probably possible to do this, but I don't have any m5stack devices, so I won't be able to do it anytime soon.

djmuerteitm, 2025-07-27:
Hi! Of course, your apps are always welcome, and i am very gratefull to you and for your dedication and time. If at any time you want to do some coding, all my stuff are able to test all you want.

Again, thanks for doing this. I'll write about jammer performance when come back from hdays.

Closed 2025-07-27.

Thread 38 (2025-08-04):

ESP32 38 pin.

Dead3ch, 2025-08-04:
Hi. I used esp32 38pin. but jammer doesn't work on it... Will it work on this board which I ordered ESP32 Wroom-32 30pin USB CH340C ?

Dead3ch, 2025-08-09:
Hello again. Will this board fit ? ESP32 D0WDQ6 Type-C.

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

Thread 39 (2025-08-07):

ESP32 30 pin without IO16 pin

aivlev00, 2025-08-07:
Hi, I am assembling the without OLED version, I connected one NRF24, everything works, but there were problems with connecting the second NRF24. I have a 30pin ESP32 Dev Kit C board and it does not have an IO16 pin to connect the second NRF24. How to connect this pin in this case?

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

Closed 2025-08-08.

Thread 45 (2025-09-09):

web UI

Ownness, 2025-09-09:
wifi ammer is not the correct password

W0rthlessS0ul, 2025-09-09:
If you are upgrading from other versions, then you need to erase flash memory of the esp32 board
Example:
esptool --port COMx erase_flash
OR
pio run --target erase

Ownness, 2025-09-09:
thx, it work

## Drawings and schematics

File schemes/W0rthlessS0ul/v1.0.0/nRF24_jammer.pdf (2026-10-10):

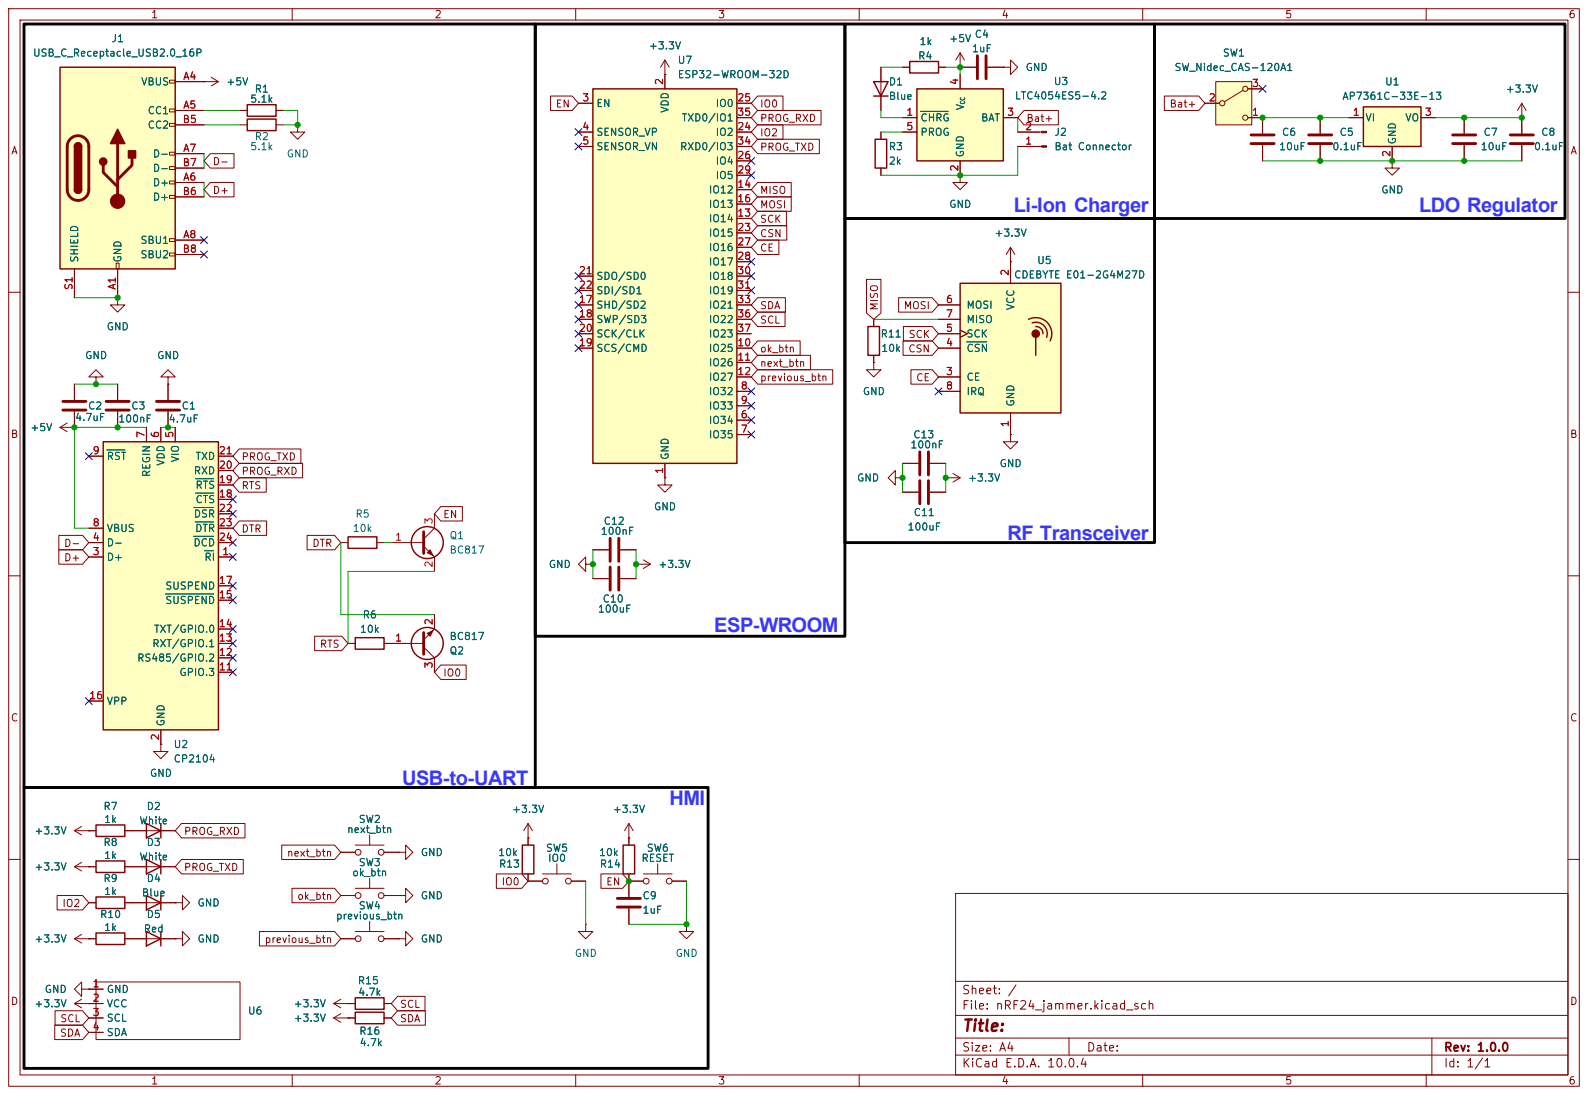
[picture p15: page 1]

Size: A4 | Rev: 1.0.0
KiCad E.D.A. 10.0.4 | Id: 1/1

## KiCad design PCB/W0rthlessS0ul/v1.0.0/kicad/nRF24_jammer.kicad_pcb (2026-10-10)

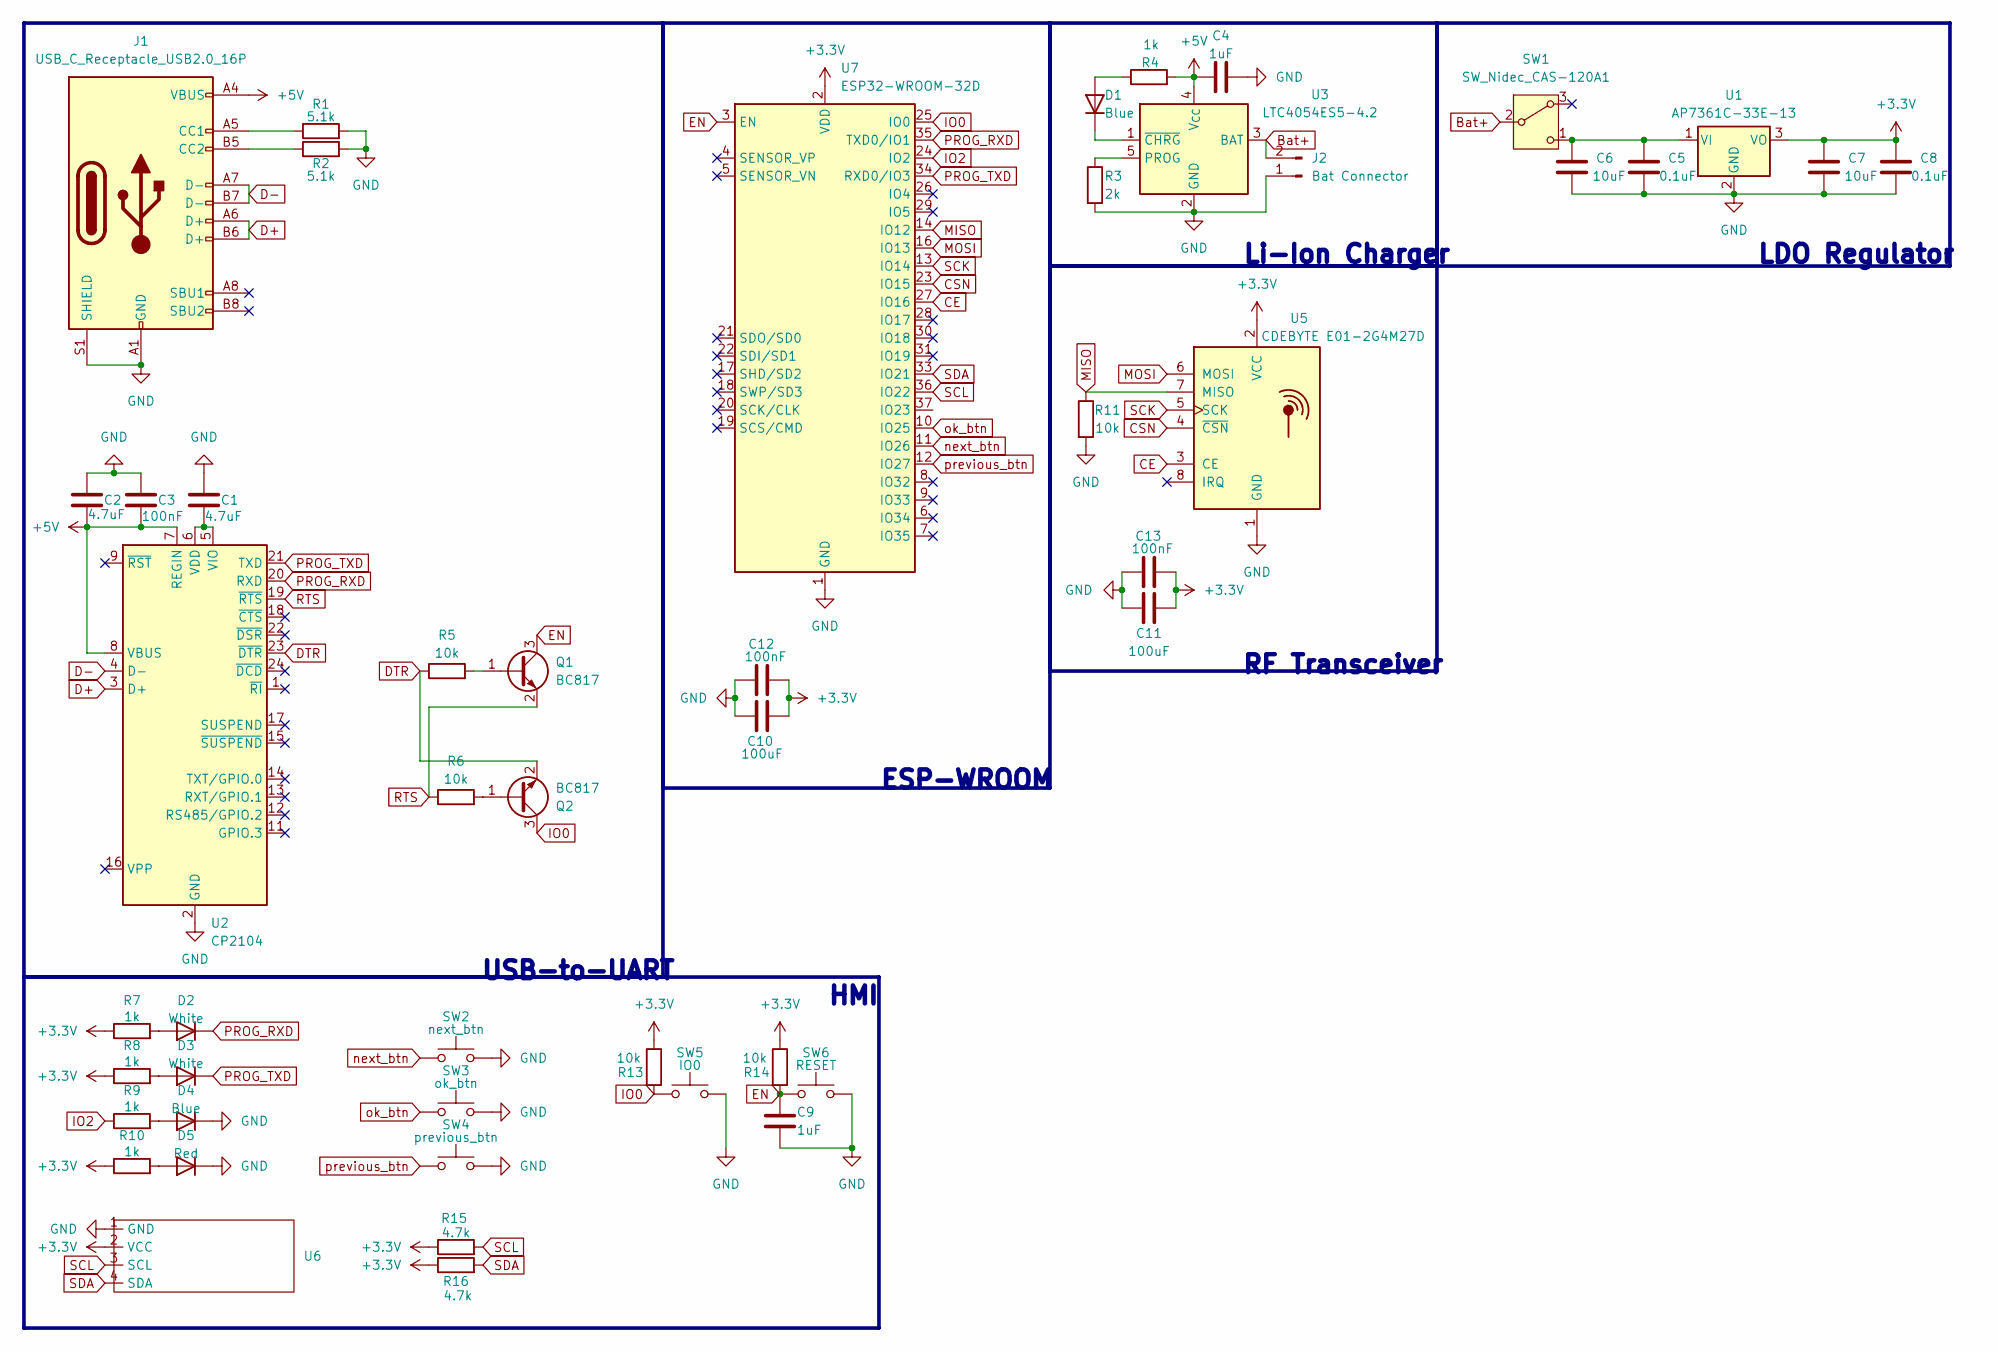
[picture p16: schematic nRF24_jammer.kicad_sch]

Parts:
C1, C2: 4.7uF; C_0603_1608Metric
C3, C12, C13: 100nF; C_0402_1005Metric
C4, C9: 1uF; C_0402_1005Metric
C5, C8: 0.1uF; C_0402_1005Metric
C6, C7: 10uF; C_0805_2012Metric
C10, C11: 100uF; C_1210_3225Metric
D1, D4: Blue; D_0402_1005Metric
D2, D3: White; D_0402_1005Metric
D5: Red; D_0402_1005Metric
J1: USB_C_Receptacle_USB2.0_16P; USB_C_Receptacle_HCTL_HC-TYPE-C-16P-01A
J2: Bat Connector; PinHeader_1x02_P2.54mm_Vertical
Q1, Q2: BC817; SOT-23
R1, R2: 5.1k; R_0402_1005Metric
R3: 2k; R_0402_1005Metric
R4, R7, R8, R9, R10: 1k; R_0402_1005Metric
R5, R6, R11, R13, R14: 10k; R_0402_1005Metric
R15, R16: 4.7k; R_0402_1005Metric
SW1: SW_Nidec_CAS-120A1; SW_Slide_SPDT_Angled_CK_OS102011MA1Q
SW2: next_btn; SW_Push_1TS009xxxx-xxxx-xxxx_6x6x5mm
SW3: ok_btn; SW_Push_1TS009xxxx-xxxx-xxxx_6x6x5mm
SW4: previous_btn; SW_Push_1TS009xxxx-xxxx-xxxx_6x6x5mm
SW5: IO0; SW_Push_1P1T-MP_NO_Horizontal_Alps_SKRTLAE010
SW6: RESET; SW_Push_1P1T-MP_NO_Horizontal_Alps_SKRTLAE010
U1: AP7361C-33E-13; SOT-223-3_TabPin2
U2: CP2104; QFN-24-1EP_4x4mm_P0.5mm_EP2.6x2.6mm
U3: LTC4054ES5-4.2; TSOT-23-5
U5: CDEBYTE E01-2G4M27D; E01-2G4M27D
U6: Display 0.96 breakout board
U7: ESP32-WROOM-32D

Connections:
+3.3V: C7.1, C8.1, C10.2, C11.1, C12.2, C13.2, R7.1, R8.1, R10.1, R13.1, R14.1, R15.1, R16.1, U1.3 (VO), U5.2 (VCC), U6.2 (VCC), U7.2 (VDD)
+5V: C2.2, C3.2, C4.1, J1.A4 (VBUS), J1.A9 (VBUS), J1.B4 (VBUS), J1.B9 (VBUS), R4.2, U2.7 (REGIN), U2.8 (VBUS), U3.4 (V_{CC})
Bat+: J2.2, SW1.2 (B), U3.3 (BAT)
CE: U5.3 (CE), U7.27 (IO16)
CSN: U5.4 (~CSN), U7.23 (IO15)
D+: J1.A6 (D+), J1.B6 (D+), U2.3 (D+)
D-: J1.A7 (D-), J1.B7 (D-), U2.4 (D-)
DTR: Q2.2 (E), R5.1, U2.23 (~DTR)
EN: C9.1, Q1.3 (C), R14.2, SW6.1, U7.3 (EN)
GND: C1.1, C2.1, C3.1, C4.2, C5.2, C6.2, C7.2, C8.2, C9.2, C10.1, C11.2, C12.1, C13.1, D4.1 (K), D5.1 (K), J1.A1 (GND), J1.A12 (GND), J1.B1 (GND), J1.B12 (GND), J1.S1 (SHIELD), J2.1, R1.2, R2.2, R3.2, R11.2, SW2.2, SW3.2, SW4.2, SW5.2, SW6.2, U1.2 (GND), U2.2 (GND), U2.25 (GND), U3.2 (GND), U5.1 (GND), U6.1 (GND), U7.1 (GND), U7.15 (GND), U7.38 (GND), U7.39 (GND)
IO0: Q2.3 (C), R13.2, SW5.1, U7.25 (IO0)
IO2: R9.1, U7.24 (IO2)
MISO: R11.1, U5.7 (MISO), U7.14 (IO12)
MOSI: U5.6 (MOSI), U7.16 (IO13)
unnamed: D1.2 (A), R4.1
unnamed: D1.1 (K), U3.1 (~CHRG)
unnamed: D2.2 (A), R7.2
unnamed: D3.2 (A), R8.2
unnamed: D4.2 (A), R9.2
unnamed: D5.2 (A), R10.2
unnamed: J1.A5 (CC1), R1.1
unnamed: J1.B5 (CC2), R2.1
unnamed: Q1.1 (B), R5.2
unnamed: Q2.1 (B), R6.2
unnamed: C5.1, C6.1, SW1.1 (C), U1.1 (VI)
unnamed: C1.2, U2.5 (VIO), U2.6 (VDD)
unnamed: R3.1, U3.5 (PROG)
PROG_RXD: D2.1 (K), U2.20 (RXD), U7.35 (TXD0/IO1)
PROG_TXD: D3.1 (K), U2.21 (TXD), U7.34 (RXD0/IO3)
RTS: Q1.2 (E), R6.1, U2.19 (~RTS)
SCK: U5.5 (SCK), U7.13 (IO14)
SCL: R15.2, U6.3 (SCL), U7.36 (IO22)
SDA: R16.2, U6.4 (SDA), U7.33 (IO21)
next_btn: SW2.1, U7.11 (IO26)
ok_btn: SW3.1, U7.10 (IO25)
previous_btn: SW4.1, U7.12 (IO27)

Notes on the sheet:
RF Transceiver
ESP-WROOM
HMI
USB-to-UART
Li-Ion Charger
LDO Regulator

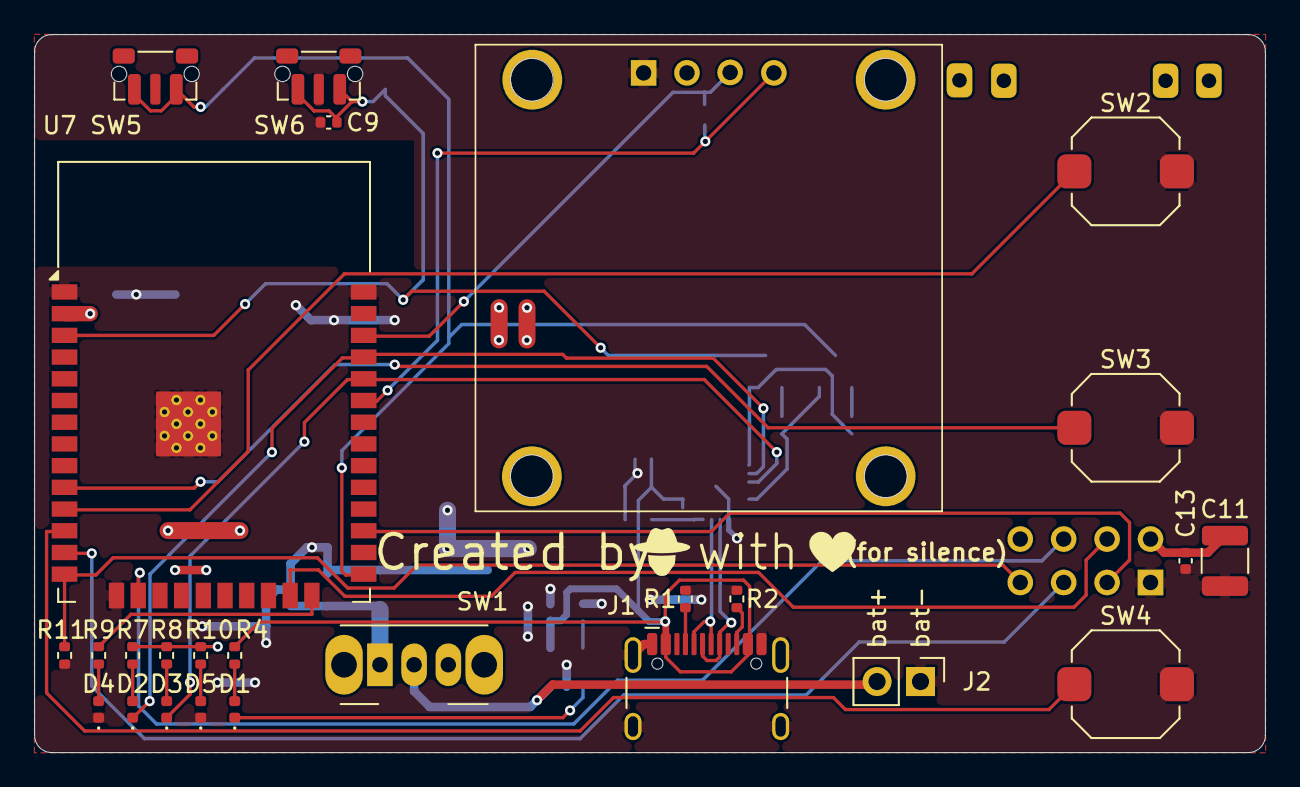
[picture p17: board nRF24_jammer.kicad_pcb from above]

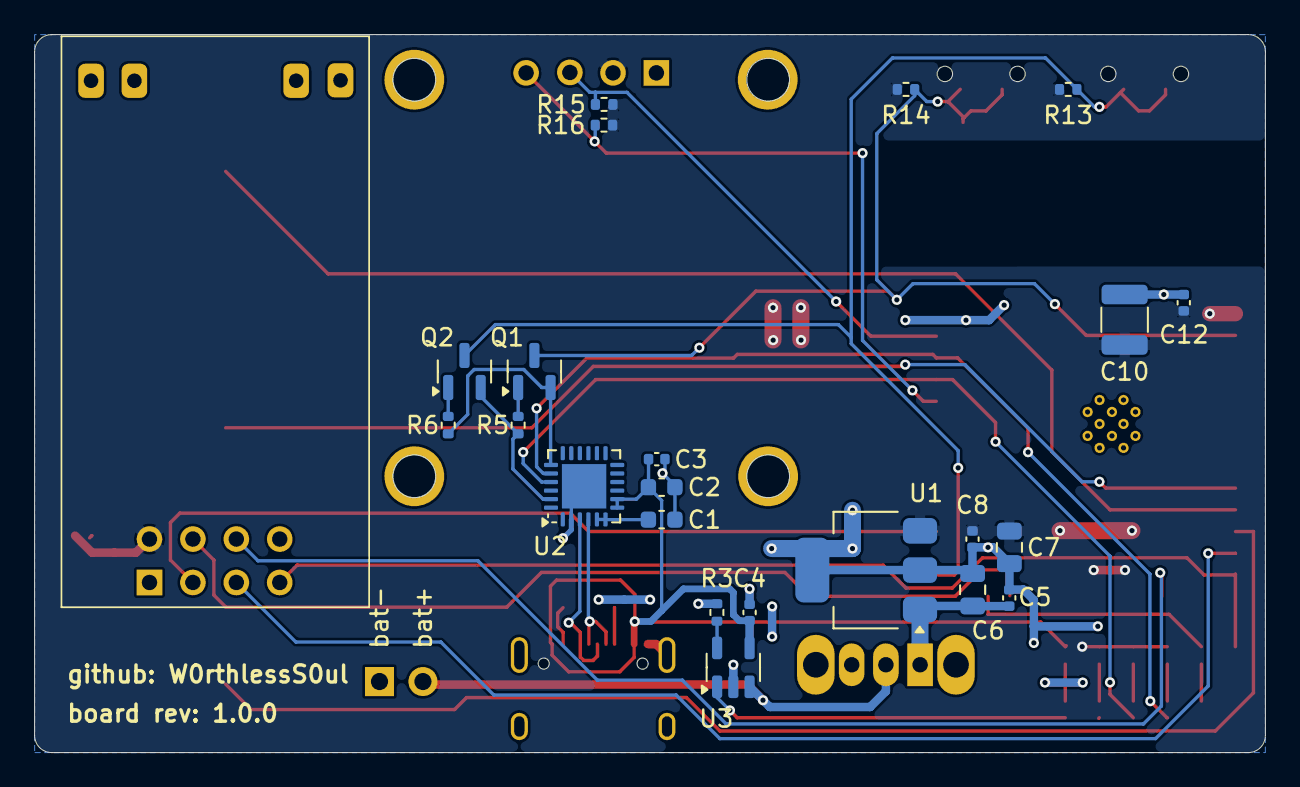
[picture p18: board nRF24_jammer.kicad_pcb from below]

Board: 2 copper layers, 72.0 x 42.0 mm, 49 parts (23 on the bottom side), 36 nets.

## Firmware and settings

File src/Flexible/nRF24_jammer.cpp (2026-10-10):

#include "bitmap.h"
#include "config.h"
#include "html.h"
#include "jam.h"
#include "scan.h"
#include "serial.h"

static String jsonEscape(const String &s)
{
  String out;
  out.reserve(s.length() + 8);
  for ( size_t i = 0; i < s.length(); i++ )
  {
    char c = s[i];
    switch ( c )
    {
    case '\\':
      out += "\\\\";
      break;
    case '"':
      out += "\\\"";
      break;
    case '\n':
      out += "\\n";
      break;
    case '\r':
      out += "\\r";
      break;
    case '\t':
      out += "\\t";
      break;
    default:
      out += c;
      break;
    }
  }
  return out;
}

void handleRoot()
{
  server.sendHeader("Content-Encoding", "gzip");
  server.send_P(200, "text/html", (const char *)html, html_len);
}

void HandleWebCommand()
{
  String command = server.arg("command");
  command.trim();
  command.toLowerCase();
  CommandsHandler(command, true);
}

void updateDisplay(int menuNum)
{
  display.clearDisplay();
  const uint8_t *bitmap = (menu_number == 0)   ? decodeLZSS((SCREEN_HEIGHT == 64) ? bitmap_bluetooth_jammer_64 : bitmap_bluetooth_jammer_32)
                          : (menu_number == 1) ? decodeLZSS((SCREEN_HEIGHT == 64) ? bitmap_drone_jammer_64 : bitmap_drone_jammer_32)
                          : (menu_number == 2) ? decodeLZSS((SCREEN_HEIGHT == 64) ? bitmap_wifi_attacks_64 : bitmap_wifi_attacks_32)
                          : (menu_number == 3) ? decodeLZSS((SCREEN_HEIGHT == 64) ? bitmap_ble_jammer_64 : bitmap_ble_jammer_32)
                          : (menu_number == 4) ? decodeLZSS((SCREEN_HEIGHT == 64) ? bitmap_zigbee_jammer_64 : bitmap_zigbee_jammer_32)
                          : (menu_number == 5) ? decodeLZSS((SCREEN_HEIGHT == 64) ? bitmap_misc_jammer_64 : bitmap_misc_jammer_32)
                                               : decodeLZSS((SCREEN_HEIGHT == 64) ? bitmap_settings_64 : bitmap_settings_32);
  display.drawBitmap(0, 0, bitmap, SCREEN_WIDTH, SCREEN_HEIGHT, WHITE);
  display.display();
}

void handlerSetSettings()
{
  baudrate             = server.arg("baudrate").toInt();
  logo                 = server.arg("logo").toInt();
  display_setting      = server.arg("display").toInt();
  SCREEN_HEIGHT        = server.arg("screen_height").toInt();
  buttons              = server.arg("button").toInt();
  Separate_or_together = server.arg("sweep").toInt();
  nrf_pa               = server.arg("pa").toInt();
  bluetooth_jam_method = server.arg("bt_method").toInt();
  drone_jam_method     = server.arg("drone_method").toInt();
  misc_jam_method      = server.arg("misc_method").toInt();
  ssid                 = server.arg("ssid");
  password             = server.arg("password");
  access_point         = server.arg("ap").toInt();
  jam_delay            = server.arg("delay").toInt();

  String beacon_list = server.arg("beacon");
  String ce_list     = server.arg("ce");
  String csn_list    = server.arg("csn");

  auto parseTokens = [](const String &str, auto callback, int maxCount) -> int {
    if ( str.length() == 0 )
      return 0;

    int count = 0;
    int start = 0;
    while ( count < maxCount )
    {
      int sep = str.indexOf('|', start);
      if ( sep == -1 )
        sep = str.length();

      String token = str.substring(start, sep);
      token.trim();

      if ( token.length() > 0 )
      {
        callback(token, count++);
      }

      if ( sep == str.length() )
        break;
      start = sep + 1;
    }
    return count;
  };

  nrf24_count = parseTokens(ce_list, [](const String &token, int idx) { ce_pins[idx] = token.toInt(); }, 30);

  parseTokens(csn_list, [](const String &token, int idx) { csn_pins[idx] = token.toInt(); }, 30);

  memset(SSIDs_Array, 0, sizeof(SSIDs_Array));
  parseTokens(beacon_list, [](const String &token, int idx) {
    String ssid_str = token.length() > 31 ? token.substring(0, 31) : token;
    strlcpy(SSIDs_Array[idx], ssid_str.c_str(), sizeof(SSIDs_Array[idx])); }, 100);

  prefs.putInt("baudrate", baudrate);
  prefs.putInt("logo_configs", logo);
  prefs.putInt("display_configs", display_setting);
  prefs.putInt("screen_height", SCREEN_HEIGHT);
  prefs.putInt("buttons_configs", buttons);
  prefs.putInt("SorT_configs", Separate_or_together);
  prefs.putInt("PA_configs", nrf_pa);
  prefs.putInt("bt_configs", bluetooth_jam_method);
  prefs.putInt("drone_configs", drone_jam_method);
  prefs.putInt("misc_configs", misc_jam_method);
  prefs.putInt("nRF24_count", nrf24_count);
  prefs.putString("ssid", ssid);
  prefs.putString("password", password);
  prefs.putInt("AP_configs", access_point);
  prefs.putInt("jam_delay", jam_delay);

  prefs.putBytes("SSIDs_Array", SSIDs_Array, sizeof(SSIDs_Array));
  prefs.putBytes("nRF24_ce_pins", ce_pins, sizeof(ce_pins));
  prefs.putBytes("nRF24_csn_pins", csn_pins, sizeof(csn_pins));

  Serial.updateBaudRate(baudrate);

  if ( SCREEN_HEIGHT == 32 )
  {
    display.ssd1306_command(SSD1306_SETCOMPINS);
    display.ssd1306_command(0x02);
    display.ssd1306_command(SSD1306_SETMULTIPLEX);
    display.ssd1306_command(0x1F);
  }
  else
  {
    display.ssd1306_command(SSD1306_SETCOMPINS);
    display.ssd1306_command(0x12);
    display.ssd1306_command(SSD1306_SETMULTIPLEX);
    display.ssd1306_command(0x3F);
  }

  server.send(200, "text/plain", "OK");
}

void handlenRF24Init()
{
  nrf24_count = prefs.getInt("nRF24_count", 0);

  prefs.getBytes("nRF24_ce_pins", ce_pins, sizeof(ce_pins));
  prefs.getBytes("nRF24_csn_pins", csn_pins, sizeof(csn_pins));
}

void handlenRF24Scan()
{
  HSPI_init();

  auto isSafePin = [&](int pin) {
    if ( !GPIO_IS_VALID_OUTPUT_GPIO(pin) )
      return false;
    switch ( pin )
    {
    case 1:
    case 3:
    case 6:
    case 7:
    case 8:
    case 9:
    case 10:
    case 11:
    case 12:
    case 13:
    case 14:
    case 22:
    case 21:
    case 25:
    case 26:
    case 27:
    case 2:
      return false;
    default:
      return true;
    }
  };
  auto readReg = [&](int csnPin, uint8_t reg) {
    hp->beginTransaction(SPISettings(1000000, MSBFIRST, SPI_MODE0));
    digitalWrite(csnPin, LOW);
    hp->transfer(0x00 | reg);
    uint8_t val = hp->transfer(0xFF);
    digitalWrite(csnPin, HIGH);
    hp->endTransaction();
    return val;
  };
  auto writeReg = [&](int csnPin, uint8_t reg, uint8_t val) {
    hp->beginTransaction(SPISettings(1000000, MSBFIRST, SPI_MODE0));
    digitalWrite(csnPin, LOW);
    hp->transfer(0x20 | reg);
    hp->transfer(val);
    digitalWrite(csnPin, HIGH);
    hp->endTransaction();
  };

  for ( int p = 0; p < SOC_GPIO_PIN_COUNT; p++ )
  {
    if ( isSafePin(p) )
    {
      pinMode(p, OUTPUT);
      digitalWrite(p, HIGH);
    }
  }

  int csn_pins_count = 0;
  for ( int csn = 0; csn < SOC_GPIO_PIN_COUNT; csn++ )
  {
    if ( !isSafePin(csn) )
      continue;

    writeReg(csn, 0x05, 0x33);
    uint8_t test = readReg(csn, 0x05);
    if ( test != 0x33 )
      continue;

    writeReg(csn, 0x05, 0x44);
    test = readReg(csn, 0x05);
    if ( test != 0x44 )
      continue;

    csn_pins[csn_pins_count] = csn;
    csn_pins_count++;
  }

  for ( int p = 0; p < SOC_GPIO_PIN_COUNT; p++ )
  {
    if ( isSafePin(p) )
    {
      bool is_csn = false;
      for ( int i = 0; i < csn_pins_count; i++ )
      {
        if ( csn_pins[i] == p )
        {
          is_csn = true;
          break;
        }
      }
      if ( !is_csn )
      {
        digitalWrite(p, LOW);
      }
    }
  }

  if ( csn_pins_count == 0 )
  {
    HSPI_deinit();
    return;
  }

  int ce_pins_count = 0;
  for ( int ce = 0; ce < SOC_GPIO_PIN_COUNT; ce++ )
  {
    if ( !isSafePin(ce) )
      continue;

    auto csn = std::find(std::begin(csn_pins), std::end(csn_pins), ce);
    if ( csn != std::end(csn_pins) )
      continue;

    for ( int i = 0; i < csn_pins_count; i++ )
    {
      int csn_pin = csn_pins[i];

      writeReg(csn_pin, 0x01, 0x00);
      writeReg(csn_pin, 0x00, 0x0E);
      delay(5);

      writeReg(csn_pin, 0x07, 0x70);

      hp->beginTransaction(SPISettings(1000000, MSBFIRST, SPI_MODE0));
      digitalWrite(csn_pin, LOW);
      hp->transfer(0xE1);
      digitalWrite(csn_pin, HIGH);

      digitalWrite(csn_pin, LOW);
      hp->transfer(0xA0);
      hp->transfer(0x55);
      digitalWrite(csn_pin, HIGH);
      hp->endTransaction();

      digitalWrite(ce, HIGH);
      delayMicroseconds(50);
      digitalWrite(ce, LOW);

      delay(5);

      uint8_t status = readReg(csn_pin, 0x07);
      if ( (status & 0x20) == 0 )
        continue;

      ce_pins[ce_pins_count] = ce;
      ce_pins_count++;
    }
  }

  if ( ce_pins_count != csn_pins_count )
  {
    HSPI_deinit();
    return;
  }

  nrf24_count = ce_pins_count;

  prefs.putBytes("nRF24_ce_pins", ce_pins, sizeof(ce_pins));
  prefs.putBytes("nRF24_csn_pins", csn_pins, sizeof(csn_pins));
  prefs.putInt("nRF24_count", nrf24_count);

  HSPI_deinit();
}

void RescanHandler()
{
  scan_wifi_APs(WiFiScanChannels, false);
  handleRoot();
}

void sendHtmlAndExecute(const uint8_t *htmlData, size_t len, void (*action)() = nullptr)
{
  server.sendHeader("Content-Encoding", "gzip");
  server.send_P(200, "text/html", (const char *)htmlData, len);
  delay(500);
  if ( action )
    action();
}

void attackHandler(String htmlResponse, void (*attackFunction)(), const unsigned char *bitmap)
{
  (void)htmlResponse;
  display.clearDisplay();
  display.drawBitmap(0, 0, bitmap, SCREEN_WIDTH, SCREEN_HEIGHT, WHITE);
  display.display();
  sendHtmlAndExecute(html_jam, html_jam_len, attackFunction);
  updateDisplay(menu_number);
}

void attackScanHandler(String htmlResponse, void (*attackFunction)(), const unsigned char *bitmap)
{
  (void)htmlResponse;
  display.clearDisplay();
  display.drawBitmap(0, 0, bitmap, SCREEN_WIDTH, SCREEN_HEIGHT, WHITE);
  display.display();
  server.sendHeader("Content-Encoding", "gzip");
  server.send_P(200, "text/html", (const char *)html_jam, html_jam_len);
  delay(500);
  if ( access_point == 0 )
    WiFi.softAPdisconnect();
  WiFi.mode(WIFI_STA);
  delay(100);
  NumberChannels = scan_wifi_APs(WiFiScanChannels, true);
  attackFunction();
  updateDisplay(menu_number);
}

void miscChannelsHandler()
{
  int channel1 = server.arg("start").toInt();
  int channel2 = server.arg("stop").toInt();

  sendHtmlAndExecute(html_jam, html_jam_len);

  display.clearDisplay();
  display.setCursor(0, 0);
  display.println("Start");
  display.setCursor(96, 0);
  display.println("Stop");
  display.setCursor(52, 0);
  display.println("Width");
  display.setCursor(8, 10);
  display.println(String(channel1));
  display.setCursor(60, 10);
  display.println(String(channel2 - channel1));
  display.setCursor(100, 10);
  display.println(String(channel2));
  display.setCursor(0, 20);
  display.println("Jamming Started");
  display.display();

  jamHandler(misc_jam, "Jamming from " + String(channel1) + " to " + String(channel2), decodeLZSS((SCREEN_HEIGHT == 64) ? bitmap_misc_jammer_64 : bitmap_misc_jammer_32), false, false, true, false, channel1, channel2);
  updateDisplay(menu_number);
}

void wifiChannelsHandler()
{
  int channel = server.arg("channel").toInt();

  display.clearDisplay();
  display.drawBitmap(0, 0, decodeLZSS((SCREEN_HEIGHT == 64) ? bitmap_wifi_jam_64 : bitmap_wifi_jam_32), SCREEN_WIDTH, SCREEN_HEIGHT, WHITE);
  display.display();
  sendHtmlAndExecute(html_jam, html_jam_len);

  jamHandler(wifi_channel, "Jamming WiFi channel", decodeLZSS((SCREEN_HEIGHT == 64) ? bitmap_wifi_jam_64 : bitmap_wifi_jam_32), false, false, false, false, channel - 1, 0);
  updateDisplay(menu_number);
}

void wifiDeauthChannelsHandler()
{
  int channel = server.arg("channel").toInt();

  display.clearDisplay();
  display.drawBitmap(0, 0, decodeLZSS((SCREEN_HEIGHT == 64) ? bitmap_wifi_deauth_64 : bitmap_wifi_deauth_32), SCREEN_WIDTH, SCREEN_HEIGHT, WHITE);
  display.display();
  sendHtmlAndExecute(html_jam, html_jam_len);

  wifi_deauth_channel(channel);
  updateDisplay(menu_number);
}

void handleApiStatus()
{
  String json;
  json.reserve(1024);

  json += "{\"nrf24_count\":" + String(nrf24_count) + ",";

  String btText;
  switch ( bluetooth_jam_method )
  {
  case 0:
    btText = "21 channels";
    break;
  case 1:
  case 2:
    btText = "80 channels";
    break;
  default:
    btText = "-";
  }
  json += "\"bt_channels_text\":\"" + btText + "\",";
  json += "\"wifi_jam_method\":" + String(wifi_jam_method) + ",";

  json += "\"ssids_by_channel\":[";
  for ( int ch = 0; ch < 14; ch++ )
  {
    json += "\"" + jsonEscape(String(APs_array[ch])) + "\"";
    if ( ch < 13 )
      json += ",";
  }
  json += "],";

  json += "\"wifi_channels\":[";
  for ( int ch = 0; ch < 14; ch++ )
  {
    json += String(WiFiScanChannels[ch]);
    if ( ch < 13 )
      json += ",";
  }
  json += "]";

  json += "}";
  server.send(200, "application/json", json);
}

void handleApiSettings()
{
  String json;
  json.reserve(2048);

  json += "{\"version\":\"" + String(Version_Number) + "\",";
  json += "\"baudrate\":" + String(baudrate) + ",";
  json += "\"logo\":" + String(logo) + ",";
  json += "\"display\":" + String(display_setting) + ",";
  json += "\"screen_height\":" + String(SCREEN_HEIGHT) + ",";
  json += "\"button\":" + String(buttons) + ",";
  json += "\"sweep\":" + String(Separate_or_together) + ",";
  json += "\"pa\":" + String(nrf_pa) + ",";
  json += "\"bt\":" + String(bluetooth_jam_method) + ",";
  json += "\"drone\":" + String(drone_jam_method) + ",";
  json += "\"misc\":" + String(misc_jam_method) + ",";
  json += "\"delay\":" + String(jam_delay) + ",";
  json += "\"ap\":" + String(access_point) + ",";
  json += "\"nrf24_count\":" + String(nrf24_count) + ",";

  json += "\"ssid\":\"" + jsonEscape(ssid) + "\",";
  json += "\"password\":\"" + jsonEscape(password) + "\",";

  json += "\"beacon\":[";
  bool firstB = true;
  for ( int i = 0; i < 100; i++ )
  {
    if ( SSIDs_Array[i][0] == '\0' )
      break;
    if ( !firstB )
      json += ",";
    json += "\"" + jsonEscape(String(SSIDs_Array[i])) + "\"";
    firstB = false;
  }
  json += "],";

  json += "\"ce_pins\":[";
  for ( int i = 0; i < nrf24_count; i++ )
  {
    json += String(ce_pins[i]);
    if ( i < nrf24_count - 1 )
      json += ",";
  }
  json += "],";

  json += "\"csn_pins\":[";
  for ( int i = 0; i < nrf24_count; i++ )
  {
    json += String(csn_pins[i]);
    if ( i < nrf24_count - 1 )
      json += ",";
  }
  json += "]";

  json += "}";
  server.send(200, "application/json", json);
}

void handleApiVersion()
{
  String json = "{\"version\":\"" + String(Version_Number) + "\"}";
  server.send(200, "application/json", json);
}

void storeEEPROMAndSet(const char *index, int value, int &targetVar)
{
  prefs.putInt(index, value);
  targetVar = value;
  server.sendHeader("Location", "/");
  server.send(302, "text/plain", "");
}

void saveWiFiSettings(const char *new_ssid, const char *new_password)
{
  prefs.putString("ssid", new_ssid);

  prefs.putString("password", new_password);
}

void handleResetWiFiSettings()
{
  saveWiFiSettings(default_ssid, default_password);

  server.sendHeader("Content-Encoding", "gzip");
  server.send_P(200, "text/html", (const char *)html_pls_reboot, html_pls_reboot_len);
  delay(1000);
  ESP.restart();
}

void handleFileUpload()
{
  HTTPUpload          &upload         = server.upload();
  static unsigned long lastUpdate     = 0;
  const unsigned long  updateInterval = 10;

  if ( upload.status == UPLOAD_FILE_START )
  {
    Serial.printf("Update: %s\n", upload.filename.c_str());
    if ( !Update.begin(UPDATE_SIZE_UNKNOWN) )
    {
      Update.printError(Serial);
      return;
    }
    else
    {
      server.sendHeader("Connection", "close");
      server.sendHeader("Access-Control-Allow-Origin", "*");
      lastUpdate = millis();
    }
  }
  else if ( upload.status == UPLOAD_FILE_WRITE )
  {
    if ( Update.write(upload.buf, upload.currentSize) != upload.currentSize )
    {
      Update.printError(Serial);
    }

    if ( millis() - lastUpdate >= updateInterval )
    {
      lastUpdate = millis();
    }
  }
  else if ( upload.status == UPLOAD_FILE_END )
  {
  }
  else if ( upload.status == UPLOAD_FILE_ABORTED )
  {
    Update.abort();
    Serial.println("Update aborted");
  }
}
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
void loop()
{
  btnOK.tick();
  btnNext.tick();
  btnPrevious.tick();

  SerialCommands();

  if ( access_point == 0 )
  {
    if ( webServerStarted )
    {
      server.handleClient();
    }
    if ( dnsServerStarted )
    {
      dnsServer.processNextRequest();
    }
  }
  if ( buttons == 0 )
  {
    if ( btnOK.isSingle() )
    {
      menu_number = (menu_number + 1) % 7;
      updateDisplay(menu_number);
    }
    if ( btnOK.isHolded() )
    {
      executeAction(menu_number);
      btnOK.resetStates();
    }
  }
  else if ( buttons == 1 )
  {
    if ( btnOK.isSingle() )
    {
      executeAction(menu_number);
    }
    if ( btnNext.isSingle() )
    {
      menu_number = (menu_number + 1) % 7;
      updateDisplay(menu_number);
    }
  }
  else if ( buttons == 2 )
  {
    if ( btnOK.isSingle() )
    {
      executeAction(menu_number);
    }

    if ( btnNext.isSingle() )
    {
      menu_number = (menu_number + 1) % 7;
      updateDisplay(menu_number);
    }

    if ( btnPrevious.isSingle() )
    {
      menu_number = (menu_number - 1 + 7) % 7;
      updateDisplay(menu_number);
    }
  }
}

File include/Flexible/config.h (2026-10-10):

#ifndef CONFIG_H
#define CONFIG_H

#include "Adafruit_GFX.h"
#include "Adafruit_SSD1306.h"
#include "DNSServer.h"
#include "GyverButton.h"
#include "NimBLEDevice.h"
#include "Preferences.h"
#include "RF24.h"
#include "Update.h"
#include "WebServer.h"
#include "WiFi.h"
#include "esp_random.h"
#include "esp_wifi.h"

#define SCREEN_WIDTH 128
#define SCREEN_HEIGHT_MAX 64
inline int SCREEN_HEIGHT;
#define OLED_RESET -1

#define default_ssid "jammer"
#define default_password "W0rthlessS0ul"
#define Version_Number "V3.5.0"
#define Version_Name "Flexible"

inline String ssid;
inline String password;

inline int menu_number;
inline int baudrate;
inline int display_setting;
inline int logo;
inline int access_point;
inline int buttons;
inline int Separate_or_together;

inline int bluetooth_jam_method;
inline int drone_jam_method;
inline int wifi_jam_method;
inline int misc_jam_method;
inline int nrf_pa;

inline byte       bluetooth_channels[] = {32, 34, 46, 48, 50, 52, 0, 1, 2, 4, 6, 8, 22, 24, 26, 28, 30, 74, 76, 78, 80};
inline byte       ble_channels[]       = {2, 26, 80};
inline const char jam_text[]           = "xxxxxxxxxxxxxxxx";
inline int        jam_delay;

inline String BLE_MAC[100];
inline int    BLE_RSSI[100];
inline String BLE_Name[100];
inline String BLE_ManufacturerData[100];
inline String BLE_Payload[100];

inline int   nrf24_count;
inline int   ce_pins[30];
inline int   csn_pins[30];
inline RF24 *radios[30];

inline bool webServerStarted = false;
inline bool dnsServerStarted = false;

inline char   SSIDs_Array[100][33];
inline String APs_array[14];
inline int    WiFiScanChannels[14];
inline int    NumberChannels;
inline char   default_SSIDs_Array[100][33] = {
    "0 Never gonna give you up",
    "1 Never gonna let you down",
    "2 Never gonna run around",
    "3 And desert you",
    "4 Never gonna make you cry",
    "5 Never gonna say goodbye",
    "6 Never gonna tell a lie",
    "7 And hurt you",
};

inline int  channel1 = 0;
inline int  channel2 = 0;
inline int  flag     = 0;
inline bool hspi     = false;

inline SPIClass        *hp = nullptr;
inline GButton          btnOK(25);
inline GButton          btnNext(26);
inline GButton          btnPrevious(27);
inline WebServer        server(80);
inline DNSServer        dnsServer;
inline Adafruit_SSD1306 display(SCREEN_WIDTH, SCREEN_HEIGHT_MAX, &Wire, OLED_RESET);
inline Preferences      prefs;

#endif

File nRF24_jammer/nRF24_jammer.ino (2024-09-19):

#include "SPI.h"
#include "Adafruit_GFX.h"
#include "Adafruit_SSD1306.h"
#include "GyverButton.h"
#include "RF24.h"
#include "bitmap.h"
#include "html.h"
#include "WiFi.h"
#include "WebServer.h"
#include "options.h"
#include "jam.h"
#include "EEPROM.h"

void handleRoot() {
    server.send(200, "text/html", html);
}

void bluetooth_jammer() {
    server.send(200, "text/html", html_bluetooth_jam);
    display.clearDisplay();
    display.drawBitmap(0, 0, bitmap_bluetooth_jam, 128, 32, WHITE);
    display.display();
    bluetooth_jam();
}

void drone_jammer() {
    server.send(200, "text/html", html_drone_jam);
    display.clearDisplay();
    display.drawBitmap(0, 0, bitmap_drone_jam, 128, 32, WHITE);
    display.display();
    drone_jam();
}

void wifi_jammer() {
    server.send(200, "text/html", html_wifi_jam);
    display.clearDisplay();
    display.drawBitmap(0, 0, bitmap_wifi_jam, 128, 32, WHITE);
    display.display();
    wifi_jam();
}

void ble_jammer() {
    server.send(200, "text/html", html_ble_jam);
    display.clearDisplay();
    display.drawBitmap(0, 0, bitmap_ble_jam, 128, 32, WHITE);
    display.display();
    ble_jam();
}

void setting_bluetooth_jam() {
    server.send(200, "text/html", html_bluetooth_setings);
}

void setting_drone_jam() {
    server.send(200, "text/html", html_drone_setings);
}

void setting_separate_together() {
    server.send(200, "text/html", html_separate_or_together);
}

void bluetooth_method_0() {
    EEPROM.write(0, 0);
    EEPROM.commit();
    server.send(200, "text/html", html);
}

void bluetooth_method_1() {
    EEPROM.write(0, 1);
    EEPROM.commit();
    server.send(200, "text/html", html);
}

void bluetooth_method_2() {
    EEPROM.write(0, 2);
    EEPROM.commit();
    server.send(200, "text/html", html);
}

void drone_method_0() {
    EEPROM.write(1, 0);
    EEPROM.commit();
    server.send(200, "text/html", html);
}

void drone_method_1() {
    EEPROM.write(1, 1);
    EEPROM.commit();
    server.send(200, "text/html", html);
}

void separate_or_together_method_0() {
    EEPROM.write(4, 0);
    EEPROM.commit();
    server.send(200, "text/html", html);
}

void separate_or_together_method_1() {
    EEPROM.write(4, 1);
    EEPROM.commit();
    server.send(200, "text/html", html);
}

void setup() {
    Serial.begin(115200);
    EEPROM.begin(EEPROM_SIZE);
    bluetooth_jam_method = EEPROM.read(0);
    drone_jam_method = EEPROM.read(1);
    ble_jam_method = EEPROM.read(2);
    wifi_jam_method = EEPROM.read(3);
    Separate_or_together = EEPROM.read(4);
    for (int i = 0; i < 5; i++) {
        if (EEPROM.read(i) == 255) {
            EEPROM.write(i, 0);
            EEPROM.commit();
        }
    }
    WiFi.softAP(ssid, password);
    server.on("/", handleRoot);
    server.on("/bluetooth_jam", bluetooth_jammer);
    server.on("/drone_jam", drone_jammer);
    server.on("/wifi_jam", wifi_jammer);
    server.on("/ble_jam", ble_jammer);
    server.on("/setting_bluetooth_jam", setting_bluetooth_jam);
    server.on("/setting_drone_jam", setting_drone_jam);
    server.on("/setting_separate_together", setting_separate_together);
    server.on("/bluetooth_method_0", bluetooth_method_0);
    server.on("/bluetooth_method_1", bluetooth_method_1);
    server.on("/bluetooth_method_2", bluetooth_method_2);
    server.on("/drone_method_0", drone_method_0);
    server.on("/drone_method_1", drone_method_1);
    server.on("/separate_or_together_method_0", separate_or_together_method_0);
    server.on("/separate_or_together_method_1", separate_or_together_method_1);
    server.begin();
    butt1.setTimeout(200);
    display.begin(SSD1306_SWITCHCAPVCC, 0x3C);
    display.clearDisplay();
    display.drawBitmap(0, 0, bitmap_logo, 128, 32, WHITE);
    display.display();
    delay(2000);
    display.clearDisplay();
    display.drawBitmap(0, 0, bitmap_bluetooth_jammer, 128, 32, WHITE);
    display.display();
}
void loop() {
    butt1.tick();
    server.handleClient();
    if (butt1.isSingle()) {
        menu_number = (menu_number + 1) % 4;
        display.clearDisplay();
        const uint8_t* bitmap = (menu_number == 0) ? bitmap_bluetooth_jammer :
                                (menu_number == 1) ? bitmap_drone_jammer :
                                (menu_number == 2) ? bitmap_wifi_jammer : bitmap_ble_jammer;
        display.drawBitmap(0, 0, bitmap, 128, 32, WHITE);
        display.display();
    }
    if (butt1.isHolded()) {
        display.clearDisplay();
        const uint8_t* bitmap = (menu_number == 0) ? bitmap_bluetooth_jam :
                                (menu_number == 1) ? bitmap_drone_jam :
                                (menu_number == 2) ? bitmap_wifi_jam : bitmap_ble_jam;

        display.drawBitmap(0, 0, bitmap, 128, 32, WHITE);
        display.display();
        switch (menu_number) {
            case 0:
                bluetooth_jam();
                break;
            case 1:
                drone_jam();
                break;
            case 2:
                wifi_jam();
                break;
            case 3:
                ble_jam();
                break;
        }
    }
}

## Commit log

2024-10-15 The updated firmware version.
    1. An error in the web interface has been fixed.
    2. The Wi-Fi password has been changed from W0rthlesS0ul to W0rthlessS0ul.
    3. Bitmap images have been redesigned.
    4. A jammer for the Zigbee protocol has been implemented (all frequency data was sourced from the internet, and I do not have Zigbee devices for validation).
    5. Control for the Zigbee jammer has been added via bitmap interface and web interface.
    6. The README.md file has been updated with new descriptions and information.
    [nRF24_jammer.ino, options.h]
2024-11-15 Support for devices without a display has been added.
    Support for devices without a display has been added.
2024-11-20 New Improvements
    A new feature has been added: the Misc Jammer, which allows users to jam specified channels.
    A feature to disable the logo during startup has also been added.
    [nRF24_jammer.ino, options.h]
2024-11-24 Code improvements that do not impact performance.
    The code has become shorter and more readable. Special thanks to 9dl.
    [nRF24_jammer.ino]
2024-11-24 The error caused by my inattention has been corrected.
    [nRF24_jammer.ino]
2024-12-09 New Improvements
    1. The logo in the web interface has been updated for a better appearance.
    2. A new feature has been added based on the idea from this issue: https://github.com/W0rthlessS0ul/nRF24_jammer/issues/9. Special thanks to samukas81 for the suggestion.
    [nRF24_jammer.ino]
2024-12-14 New Improvements
    1. Improved web interface.
    2. The error with the OTA update has been fixed.
    3. The option to disable the access point has been added. (Thanks to samukas81 for the idea.)
    [nRF24_jammer.ino, options.h]
2025-02-06 New Improvements
    The option to use one, two, or three buttons for control has been added. (Thanks to [shuixing1122](https://github.com/shuixing1122) for the idea.)
    - A Compact version has been added
    - The standard version with two nRF24 is now called Standard
2025-02-08 New Improvements
    Added the ability to exit the jamming mode by pressing the OK button (25 pin).
    [nRF24_jammer.ino, options.h]
2025-05-21 new version
    The library is now modified + bug fixed in "compact" versions
    [nRF24_jammer.ino]
2025-06-02 new version
    1. Increased button hold delay to up to 600 ms for better press detection (Thanks to [McVillano](https://github.com/McVillano) for the idea)
    2. Reduced the delay for click buttons, making the interface more responsive
    3. Fixed a bug that prevents attacks from resuming after being stopped (Thanks to [samukas81](https://github.com/samukas81) for detecting the error)
    [nRF24_jammer.ino]
2025-07-05 new version (2.5.2)
    1. Fixed a bug that could cause the jammer to not work on all channels or not work at all
    2. Refactored code structure: moved function implementations from headers (*.h) to *.cpp files, keeping only declarations in headers
    3. All used libraries have been added to the /lib folder
    [jam.cpp, nRF24_jammer.cpp, nRF24_jammer.ino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]
2025-07-21 added schemas
    [BOM.csv]
2025-11-21 new version (2.8.0)
    1. Added firmware version display on the OTA update page
    2. Added the ability to configure nRF24 pins via the Serial interface
    3. The Serial interface now outputs 'ok' after sending a response
    4. The Serial 'info' command now includes the firmware version number, firmware type, and screen size
    5. Added the ability to disable the display via the Web and Serial interfaces
    6. The Web and Serial interfaces now display the current value of settings
2026-01-08 new version (2.9.0)
    Added the ability to send commands for the Serial interface using GET requests
    Added the ability to configure the power amplifier level
    Web interface has been improved
    Fixed a bug in misc jammer
    A Serial terminal has been added to the Web interface
    Fixed a bug in zigbee jammer (thanks yashikada)
    [jam.cpp, nRF24_jammer.cpp, options.h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]
2026-01-08 new version (2.9.0)
    One more fixed a bug in zigbee jammer (thanks yashikada)
    [jam.cpp]
2026-01-08 new version (2.9.0)
    One more fix
    [nRF24_jammer.cpp]
2026-02-07 new version (3.0.0)
    - Bug fixed in misc jammer
    - The PA setting has been added to serial settings
    - Web interface adapted for mobile devices
    - Captive portal added – redirects to control panel on connect
    - Fixed a flaw in wifi select
    - Added APs count per WiFi channel in WiFi Select
    - Added Smart Jam attack to WiFi attacks
    - Added platformio.ini and copy_files.py for easier project compilation
    [BOM.csv]
2026-02-13 new version (3.0.1)
    Correcting dumb mistakes
    [jam.cpp, nRF24_jammer.cpp, serial.cpp]
2026-02-25 new version (3.1.0)
    Added SSID display in WiFi Select Channel (idea ElberTavares)
    Completely redesigned control via Serial
    The scan sub-item has been added to Serial
    Added separation of BLE into Advertising Channels and Data Channels
    Replaced GET requests with POST/redirect for settings updates
    WiFi All added support for 14 channels
    WiFi attacks bug fixed
    Fixed a bug with the PA level installation
    [jam.cpp, nRF24_jammer.cpp, options.h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]
2026-03-06 Added a donation button
2026-04-20 new version (3.2.0)
    - Added Deauth attack (Thanks ElberTavares)
    - Added BLE scanner to serial
    - Added a settings file for clang-format
    - Fixed a bug in WiFi channel jam
    - The attack sub-item has been added to Serial
    [config.h, jam.cpp, nRF24_jammer.cpp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]
2026-06-13 Hardened AP startup before DNS
    Added explicit AP mode initialization and short settle delay before SoftAP start. This prevents possible bootloops.
    [nRF24_jammer.cpp]
2026-06-21 new version (3.3.0)
    - Added WiFi Beacon Spam (Thanks ElberTavares)
    - Switching from EEPROM library to Preferences
    - Added separation of tasks by cores, during jamming
    - Fixed a bug in random jamming methods (Thanks reimerp)
    - Fixed a bug with duplicate random values
    - Fixed bug with non-disconnecting AP (Thanks Suyu-san for finding bug)
    - Added .gitignore (Thanks spongeball)
    - Added Explicit initialization of AP (Thanks spongeball)
    - Fixed bugs from the prematurely released 3.3.0 release (Thanks BULLETPROOF-IO-SYSTEMS for finding bugs)
    - The ported firmware section moved to README.md
    [attack.cpp, config.h, jam.cpp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]
2026-10-10 new version (3.5.0)
    Added official PCB design (v1.0.0) by @W0rthlessS0ul
    Now a single firmware is used for OLED displays with a resolution of 128x64 and 128x32 pixels
    Settings menu has been added to the control via OLED
    Added foolproof binary validation to Web OTA update
    Added automatic search for connected nRF24
    Added a screen size adjustment menu
    Added jam delay settings
    Added baudrate settings
    Web interface has been translated to REST API / AJAX
    LZSS compression is now used for bitmaps
    Gzip compression is now used for htmls
    Fixed a bug in beacon spam (Thanks @djmuerteitm for finding bug)
    Fixed a bug in deauth attack
    Fixed a bug in WiFi select
    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
    [button.stl, caseBack.stl, caseFront.stl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]
2026-10-15 Fixed link to the BOM file
